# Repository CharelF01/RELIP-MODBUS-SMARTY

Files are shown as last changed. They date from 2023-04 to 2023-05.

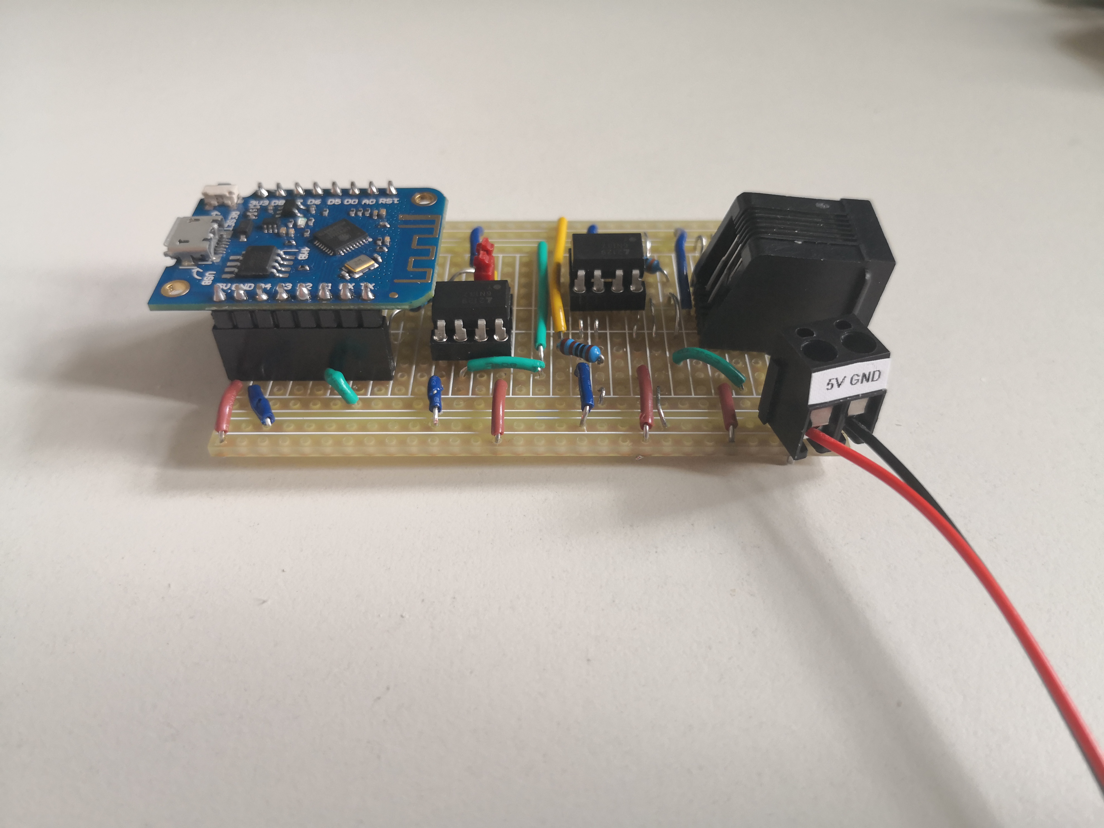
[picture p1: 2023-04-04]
Photos/Smarty Simulator/IMG_20230223_134927.jpg

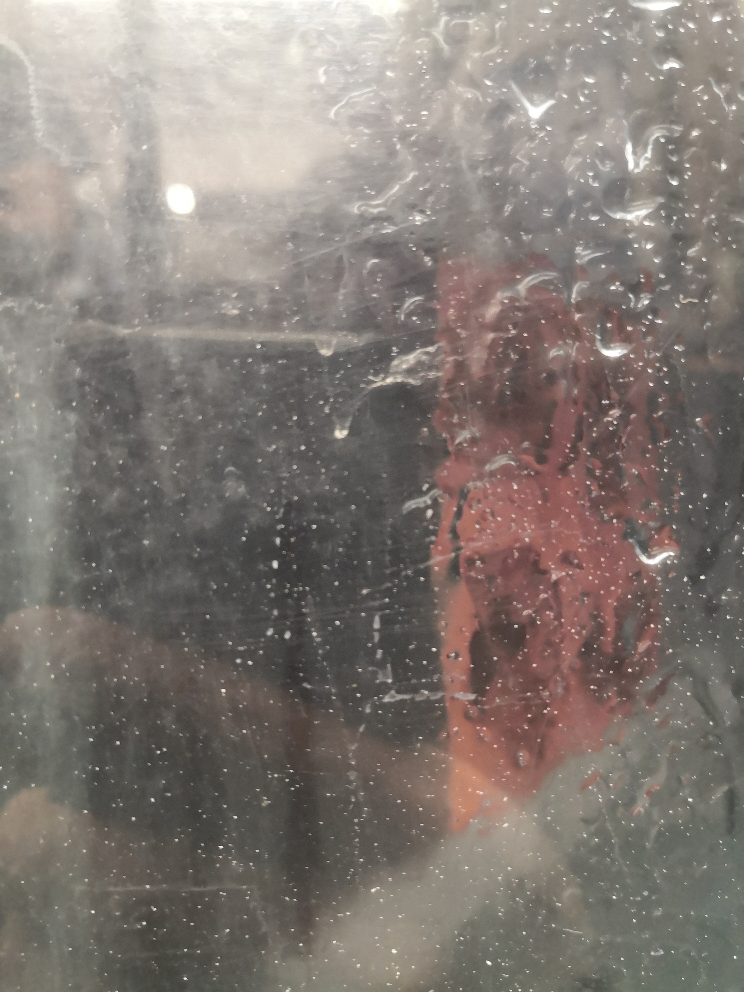
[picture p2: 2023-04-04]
Photos/Smarty Modbus/IMG_20230323_113627.jpg

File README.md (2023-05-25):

# RELIP
This project was done in the scope of the BTS-Internet of Things in the Lycée des Arts et Métiers Luxembourg with the help of Bâtiment Public Luxembourg.
The Real Life Project's objective was to make a functioning device that decrypts the data from the luxembourgish smart electrical meter and sends it out via ModBus TCP and/or RTU.

Mark received on Project: 17.5/20

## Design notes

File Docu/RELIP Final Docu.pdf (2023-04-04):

# RELIP SMARTY MODBUS

Feil Charel

### MARCH 31, 2023

BTS-IOT
Lycée des Arts et Métiers
Real Life Project 2022/2023 1, rue de l’école,
Bissen L-7768
RELIP
Supervisors:
THIERRY BERNARD
JEAN DAUBENFELD
ROBERT FISCH
GILLES GARDULA
GAETAN HOLDERBEKE
GUY WEILER

Feil Charel | 31.03.2023

## Table of contents

1 | Description of the task | 2
2 | Introduction | 3
2.1 | Step by step description | 3
3 | Main Part | 4
3.1 | List of material/ electronics | 8
3.2 | Logical schema of my infrastructure | 10
3.3 | Electronic circuit schema | 12
3.4 | Pictures of the final product | 15
3.5 | Testing table | 4
3.6 | Description of firmware | 17
3.7 | Retrospective analysis | 21
3.8 | Market analysis | 21
4 | Executive summary | 22
5 | Bibliography and list of sources | 23
6 | Executive summary | 7
7 | Acknowledgements | 24
8 | Declaration of autonomy | 25

## 1 Description of the task

The project given by our teachers consisted of 2 main parts.
Firstly, we needed to build a smarty simulator. We needed to do this as a convenience and safety measure for the class. This would enable us to work on our main projects the whole time without needing to wait for another person to be finished using the only smarty meter that we have. To build this we had a limited timeframe in order to being able to finish the main project in time. By the end of the given deadline, the smarty simulator needed to be working 100% and we needed to make a report on how and what we did.
Secondly, the main project was to build a smarty reader, which can decrypt the data received from the smarty simulator/meter and send it out via Modbus TCP and Modbus RTU. Furthermore, our product needed to be easily configurable by the end user.

## 2 Introduction

## 2.1 Step by step description

2.1.1 Smarty Simulator

My simulator simply sends out data when it’s connected to a power source of 5 Volts. However, for it to be able to send the data, you need to remove the only jumper on the board while bootup, because the connected pin is needed for the boot sequence. Afterwards, you put the jumper back on and the simulator will send data when the required triggers arrive. These are that a request is being sent to the simulator and that a non-blocking delay of 10 seconds has been passed. Then it will send data to the receiver on the other end. The simulator only sends pre configured data, which is hardcoded into the microcontroller. This is good to check reliability and be sure that all the data received by the reader is the data sent.

2.1.2 Smarty Modbus

My smarty Modbus device consists of three parts.
The configuration, which at first startup or after a reset is being shown on the access point at the IP address http://192.168.168.168 , which was given by our teachers. In this configuration, the end user can firstly decide whether they want to use RTU (RS485), TCP/IP (over ethernet) or WIFI (also TCP/IP, but named differently to reduce confusion). These are three different pages where the end user can enter all the necessary details for a successful configuration and operation.
The encryption key needs to be entered on all of the configuration pages.
In the RTU configuration page, the end user needs to enter the bitrate for the Modbus line, the slave address and the configuration for the transmission, so the Stop bit and parity.
In the TCP/IP configuration page, the end user needs to enter the IP addresses for the device itself, the gateway, subnet and DNS.
The WIFI configuration page is nearly the same as the TCP/IP one, only that the end user needs to enter the WIFI SSID and password additionally to the IP addresses asked.
After having entered all the data for the selected transmission mode, the end user needs to press the “Submit” button and the data is being saved on the device and it restarts.
The Access point reopens after bootup, so that the end user has the ability to reset the device if needed. If it isn’t necessary, the end user needs to wait 2 minutes and then the main program for the transmission via the selected Modbus is being started.

## 3 Main Part

## 3.1 Project progress

3.1.1 Smarty Simulator

3.1.1.1 Initial thoughts
One of the first things I did when we got the assignment and deadline for the simulator was to research how the optocouplers we needed to use work. Then I needed to firstly draw a functioning circuit and solder it in place on a circuit board given by our teachers. (Note to avoid confusion: the circuit wasn’t etched on the board)
At the beginning of this task, I thought that this could go rather fast if all things go well and I could focus earlier on the main part of the project.
3.1.1.2 Research
I mainly researched how the optocouplers worked, because I’ve never worked with these chips and I wanted and needed to understand them before using them. During my research, I found this fitting picture:

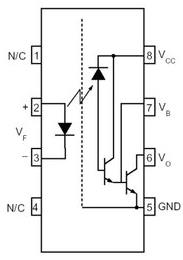
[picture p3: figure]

Then I needed to research the datasheet for the optocouplers and to calculate the needed resistors accordingly.

As shown in the picture, the input and output side are isolated (indicated by the dotted line). The input signal is transmitted via an LED on the input side to a light sensitive diode, which then activates the transistors to put out the signal on the output pin.

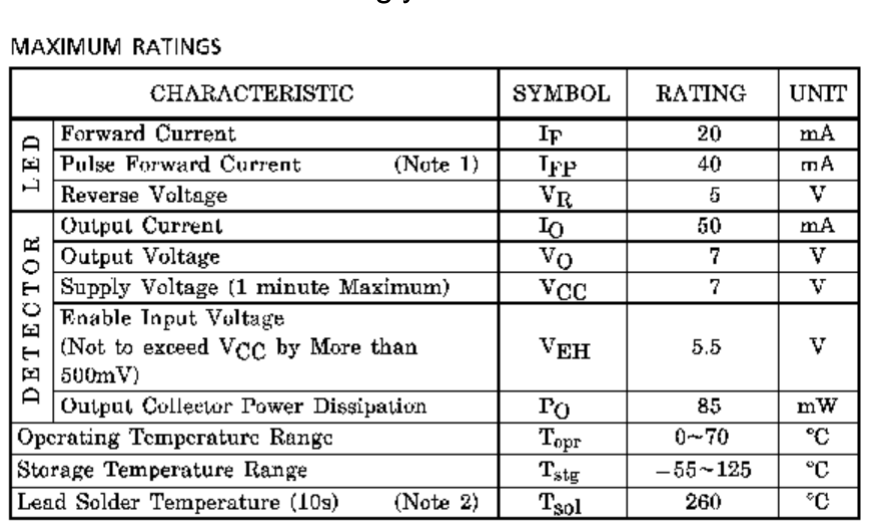
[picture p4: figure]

3.1.1.3 Calculations
The operating voltage for the internal LEDs is written as 1,7V and the maximum current is 20mA. I took 10mA as the forward current to not overstress the LED. The calculations needed to be done twice, once for the 5V side, from the RJ12 port and once for 3,3V for the ESP8266 side.
The calculations: ⁵V−1.7V
10mA

= 330Ω |

3.3V−1.7V
10mA

= 160Ω

3.1.1.4 Drawing the schematic
Then I researched examples on how to connect an optocoupler and found out that the output pin needs to be pulled up to 5V, so VCC (in most cases) or to the wanted voltage. In our case, the side going to the RJ12 port needed to be pulled up to 5V and the side going to the ESP8266 needed to be pulled up to 3,3V. In the beginning, I had both sides pulled up to 5V, which I thankfully realized in time with some help. Before putting all the components together, I drew a schematic in Eagle and asked to verify the circuit before I built it.

3.1.2 Smarty Modbus

3.1.2.1 Initial thoughts
One of the first things I thought when asked to make this product was that I had no Idea how Modbus worked and how to decrypt the received data from the smarty. We needed to do this already in an exercise during our course, but I didn’t finish it because I didn’t understand it that well that time. The decryption would become my main focus at the beginning of the project, because this seemed to be the biggest hurdle for myself at that time.
For the RS485, I knew that we needed to use a similar chip than the one we used in an exercise during our course, so I didn’t worry about that too much.
3.1.2.2 First tests
The first thing I wanted to get working was the receiving of the data and the decryption, because as I stated before, these were my main concerns at the beginning. To save some time later, I already used the RS485 chip as my serial port for debugging, which was no issue at all.
It took me some time to receive all the data correctly, but eventually I got it. Then I concentrated on the decryption, which previously gave me some headaches, but in this project it all came together, and I finally understood how to use the given libraries and could interpret the data correctly.
The next thing I tested was the Ethernet module, for that I needed the Ethernet library and simply connect the module to the ESP8266. To make sure that the module would connect to the network, I took an example code from the library and tested the connection and if it would automatically reconnect if the cable was pulled out and plugged back in.
After that, I tested the Modbus RTU with the RS485 chip by simply adding some registers and adding random values into these registers. I had some issues with this, because the software I used for reading out these registers often gave me an error that the request timed out or an invalid data request.
3.1.2.3 Managing the project
My main focus of the project was the code, because we needed to deliver something that works, and the code and the circuit are the most important pieces to this.

This means that I dedicated most of my time to the code and making sure everything would work as I intended. This was more work than I initially anticipated, but I managed to finish in time. This resulted in the design lacking a bit of finishing, but overall, I’m happy with my time management of this project.
3.1.2.4 Code
My code is far bigger than I anticipated and I’m certain that I could save a lot of space if I were to optimize some functions or write it differently, but it works the way I intended it. It was my main focus, so I dedicated all my time to this, that it works and not so much on the case. I had a lot of problems at the beginning to receive the data correctly and to decrypt the message, but I managed to do it successfully in a few days. Then I needed to concentrate on where and how the values from the smarty meter would be saved.
This took a lot more time than I anticipated, I made a lookup table consisting of the OBIS codes received from the smarty meter, their description, the register where it begins to save into, how many registers are being used for that value and a multiplication value to make the values the same unit as the ones from the SOCOMEC, which all of us based ourselves on. This took so long because many values from the smarty weren’t read by the SOCOMEC and therefore not saved in their registers. This led to a lot of confusion whether we needed to save these in random registers or not at all and some separated values from the smarty were only one register in the SOCOMEC, which meant that we needed to make a conversion. There was a lot of confusion around where to save everything, but in the end, I think everyone managed to use the same registers for everything and has their data in the same units. 3.1.2.5 Making the PCB
The PCB design was done only in a few days, because of the time constraints to get the code working properly and the availability of the room to make the PCB itself. The routing was a bit difficult, but in the end I managed to get everything routed correctly, except the one error I already mentioned in the circuits which still persists in my PCB. It still works, but this could explain some errors while reading from the RS485. 3.1.2.6 Designing the case
The case design was one of the last steps I made for this project, because it was obvious from the task given that the product needs to be working at the end and not necessarily need to look the best.
I based it all off of my PCB and designed the case around it so that it would hold the PCB in place, fit into the smarty and that the ports are accessible from the front. First idea:

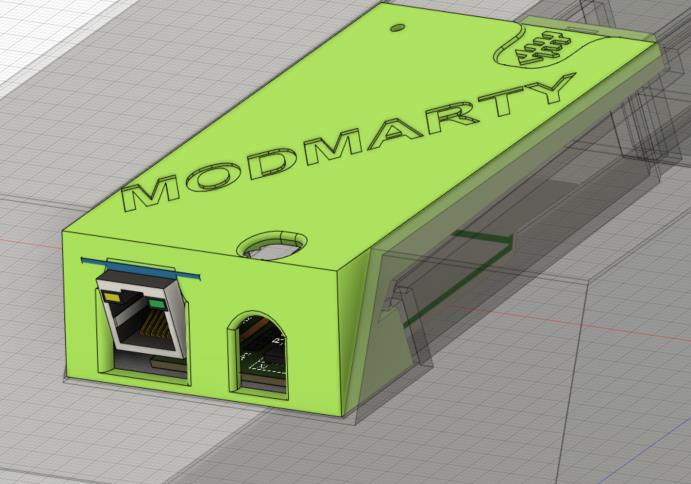
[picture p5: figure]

Final Design:

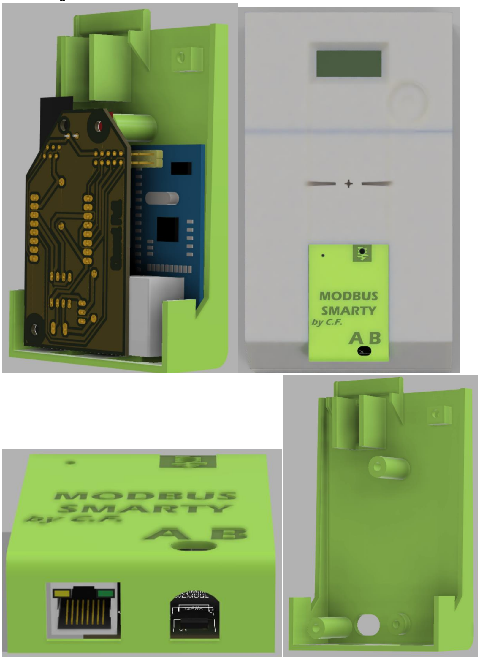
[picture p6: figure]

In my final design, I also implemented a screw hole on the upper left corner to screw the device in place. I also made some flanges to keep the cable in place on the bottom.

## 3.2 List of material/ electronics

3.2.1 Smarty Simulator

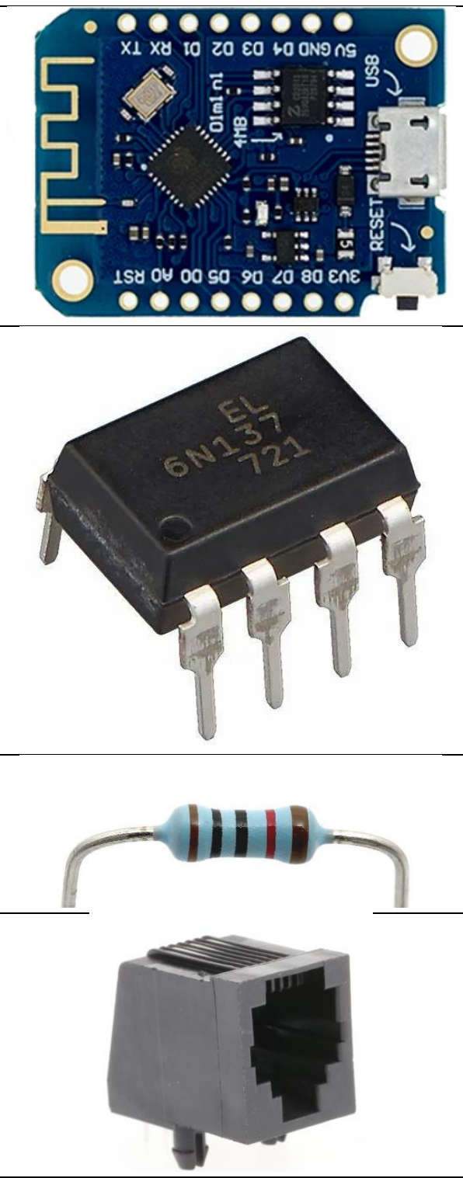
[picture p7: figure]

ESP8266

Optocoupler 2x

Resistor 3x

RJ12 Connector

3.2.2 Smarty Modbus

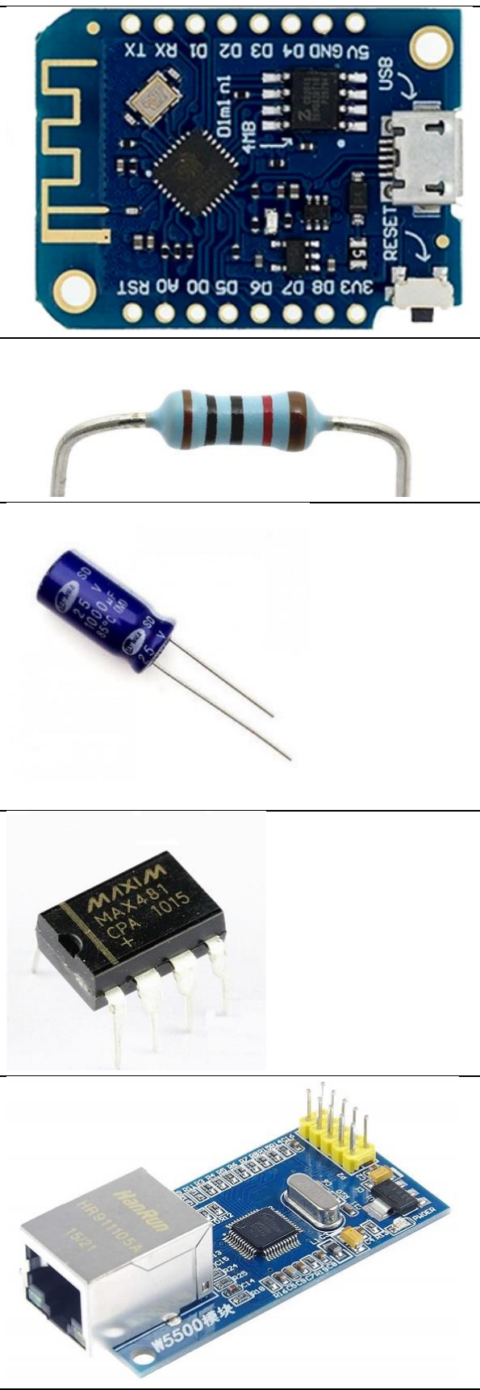
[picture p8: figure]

ESP8266

Resistor 2x

1000uF Capacitor

MAX485 CPA

Ethernet Module W5500

## 3.3 Logical schema of my infrastructure

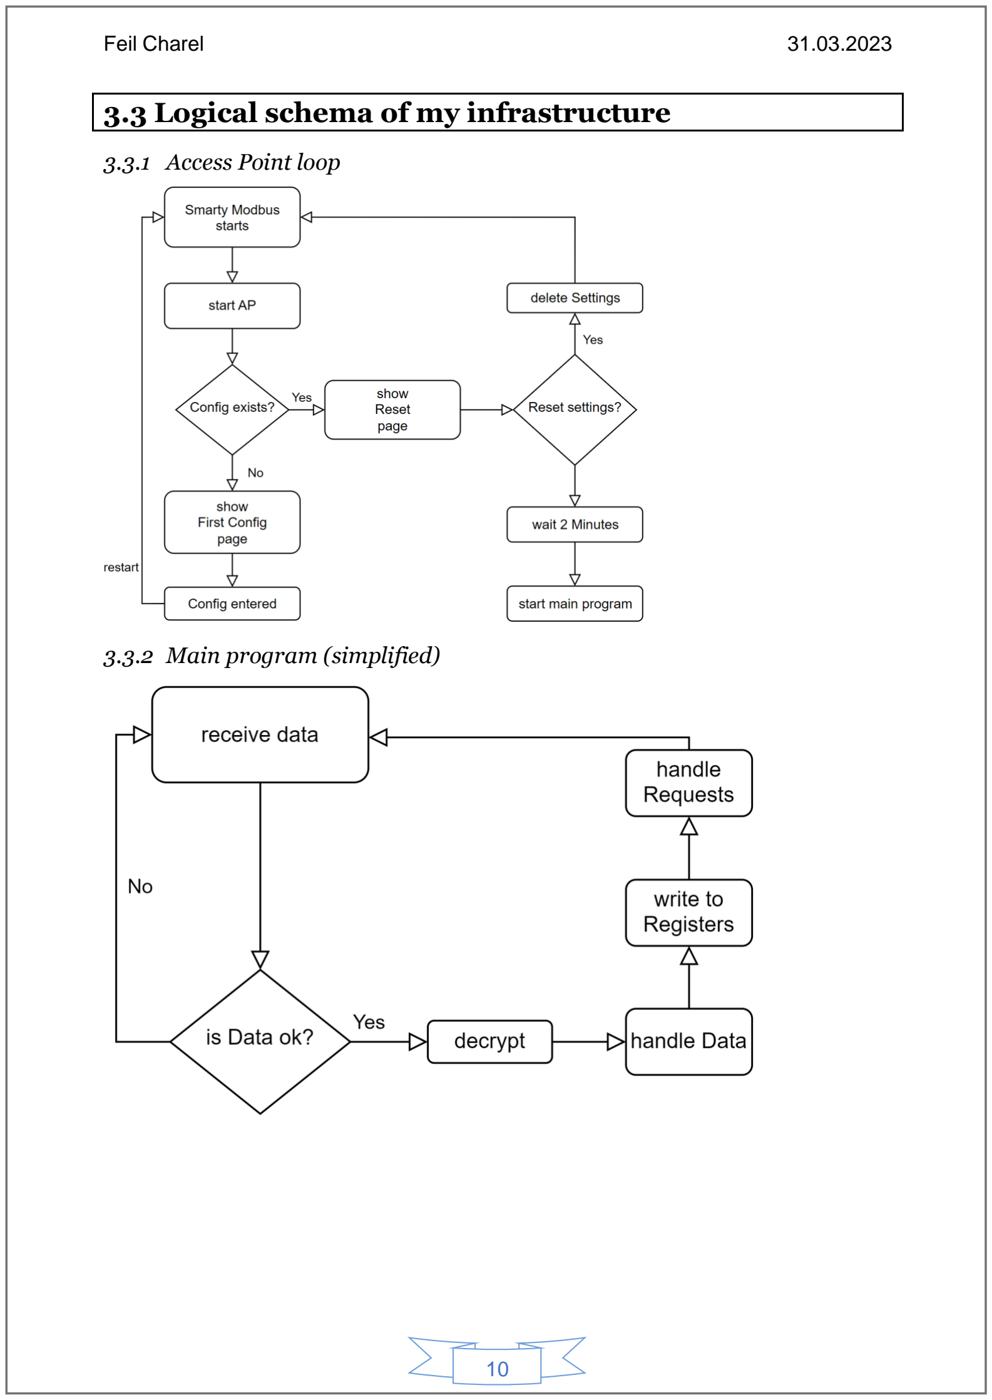
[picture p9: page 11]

3.3.1 Access Point loop

3.3.2 Main program (simplified)

3.3.3 Lookup Table

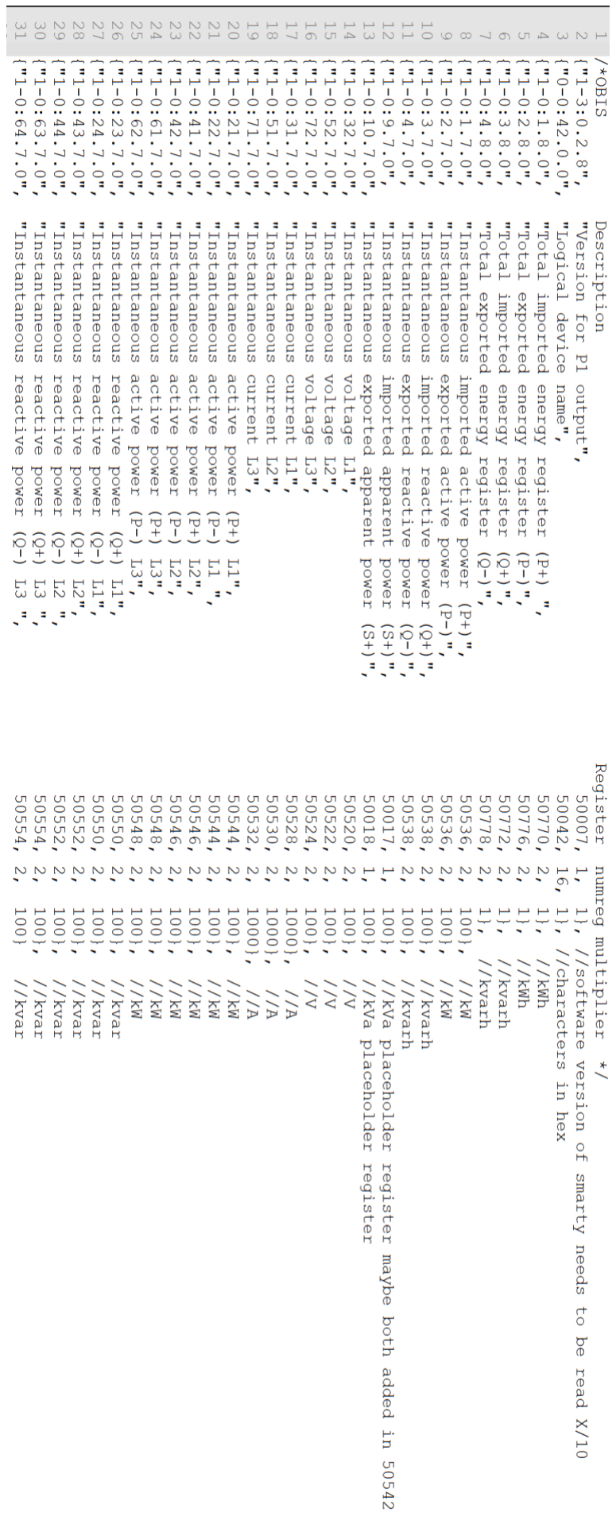
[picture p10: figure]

## 3.4 Electronic circuit schema

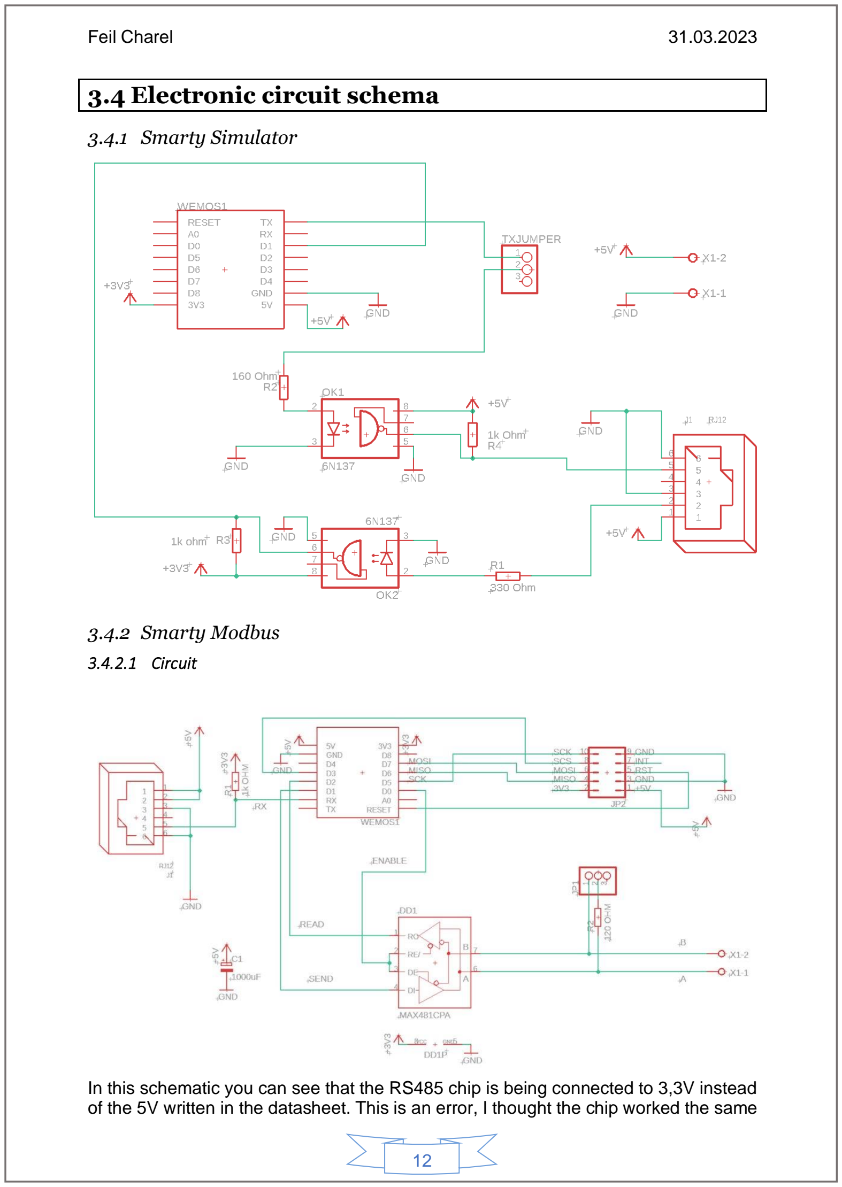
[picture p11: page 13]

3.4.1 Smarty Simulator

3.4.2 Smarty Modbus

3.4.2.1 Circuit

In this schematic you can see that the RS485 chip is being connected to 3,3V instead of the 5V written in the datasheet. This is an error, I thought the chip worked the same

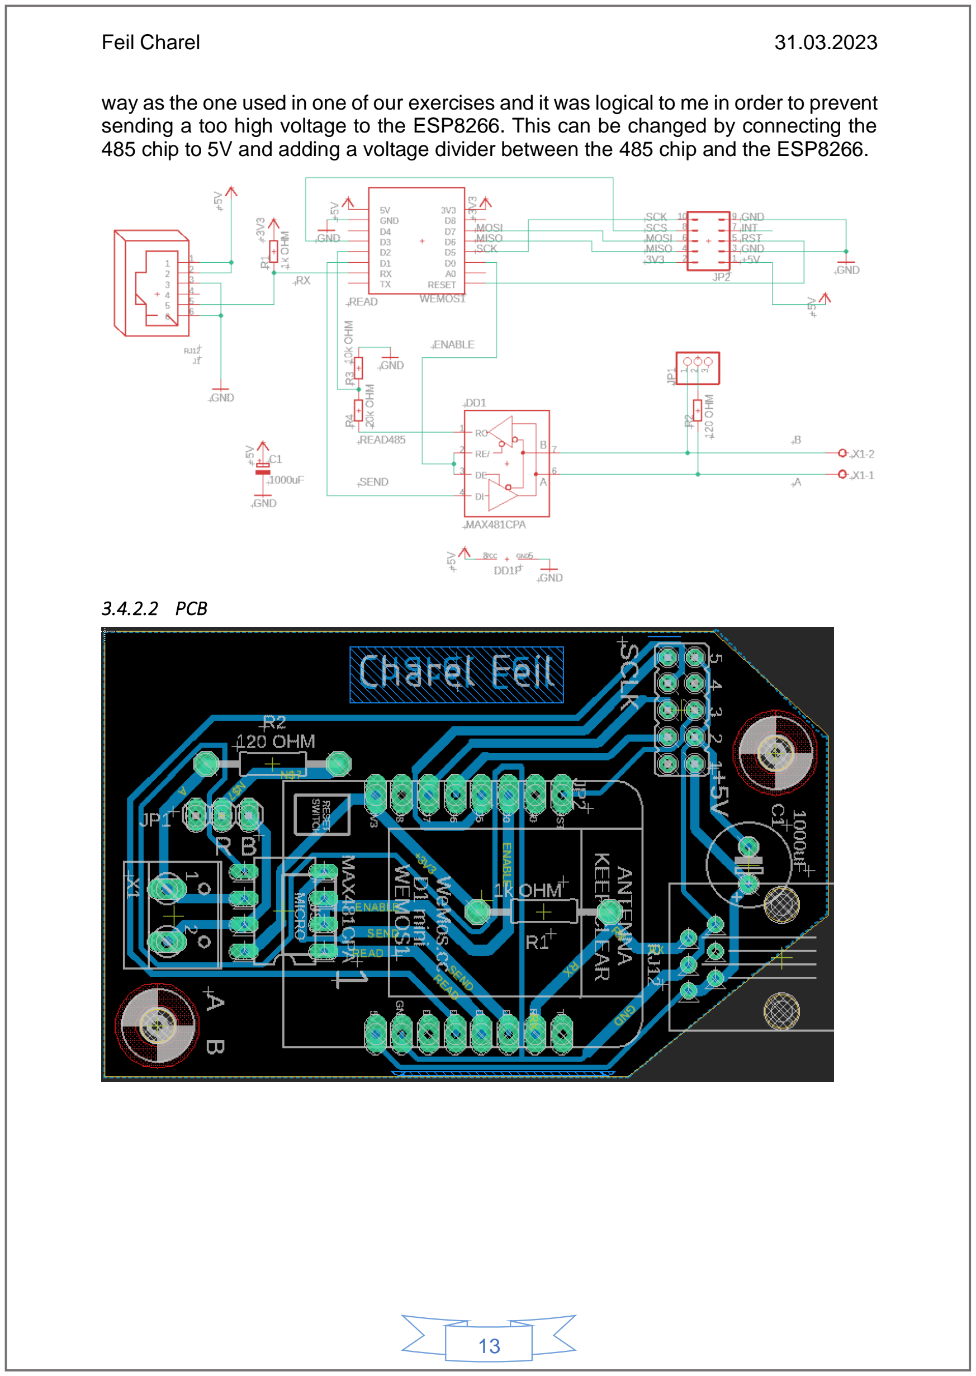
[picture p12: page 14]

way as the one used in one of our exercises and it was logical to me in order to prevent sending a too high voltage to the ESP8266. This can be changed by connecting the 485 chip to 5V and adding a voltage divider between the 485 chip and the ESP8266.

3.4.2.2 PCB

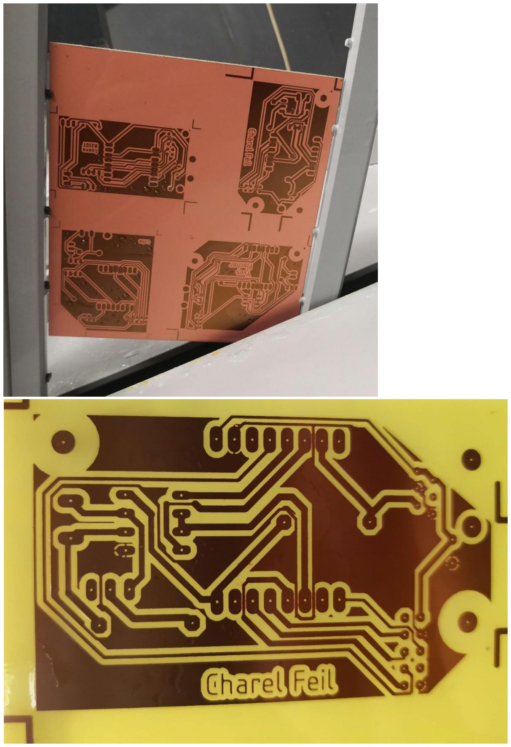
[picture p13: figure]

## 3.5 Pictures of the final product

3.5.1 Smarty Simulator

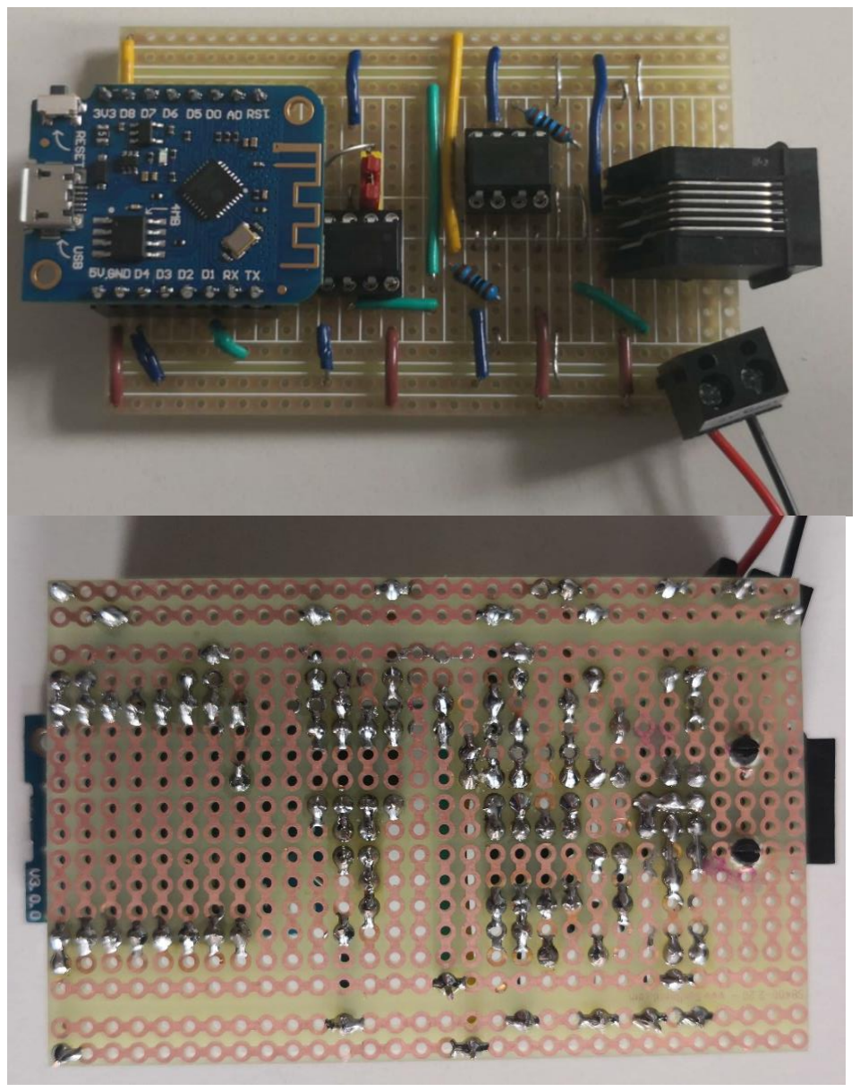
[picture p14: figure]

3.5.2 Smarty Modbus

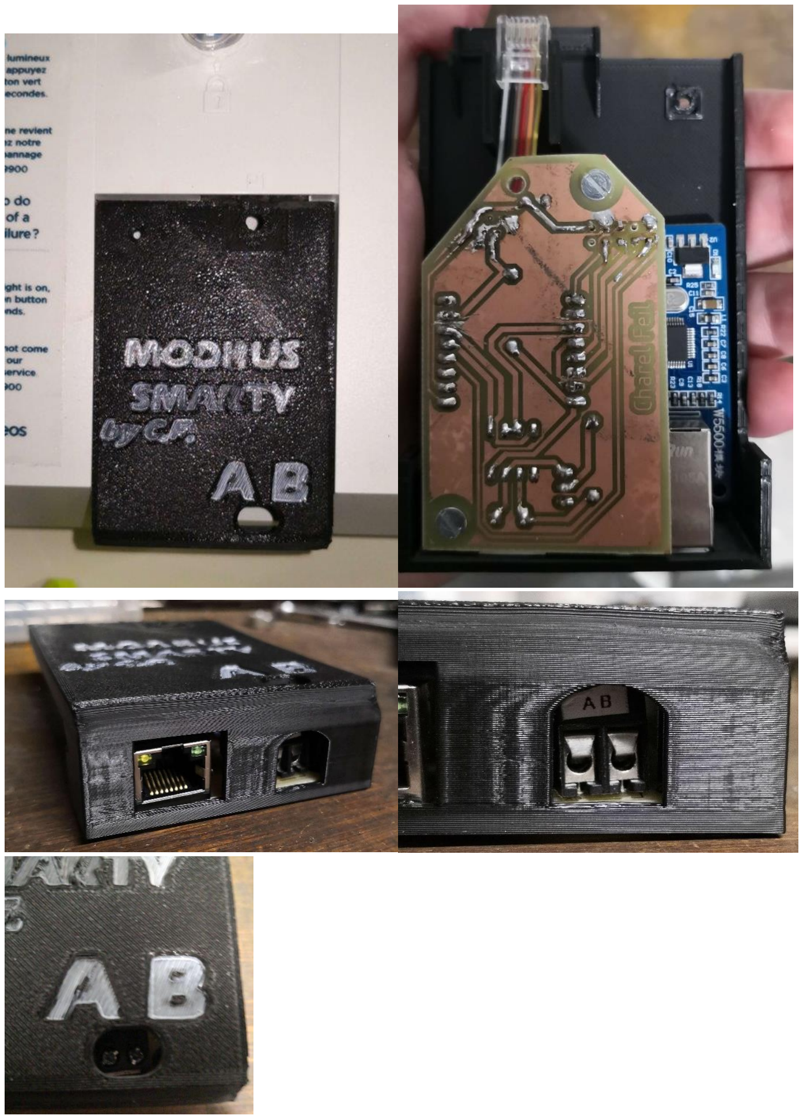
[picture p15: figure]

## 3.6 Description of firmware

You can find the flowcharts explaining the code roughly here.
When my device first boots up, it starts an Access Point (from hereon AP) under the name “Charel AP” (to avoid confusion in class), if the product were to be released to the public, I would change the name to a more appropriate one. After the AP is started, the device looks if a configuration has already been saved on it. If it hasn’t found one, then it continues to show the configuration pages to the user under the IP Address http://192.168.168.168. I made 3 different pages for RTU, TCP/IP and TCP/IP over WIFI, the starting page is RTU, so the user already sees some input and not only 3 closed tabs are being shown. The encryption key always needs to be entered, but The first configuration page of RTU looks like this:

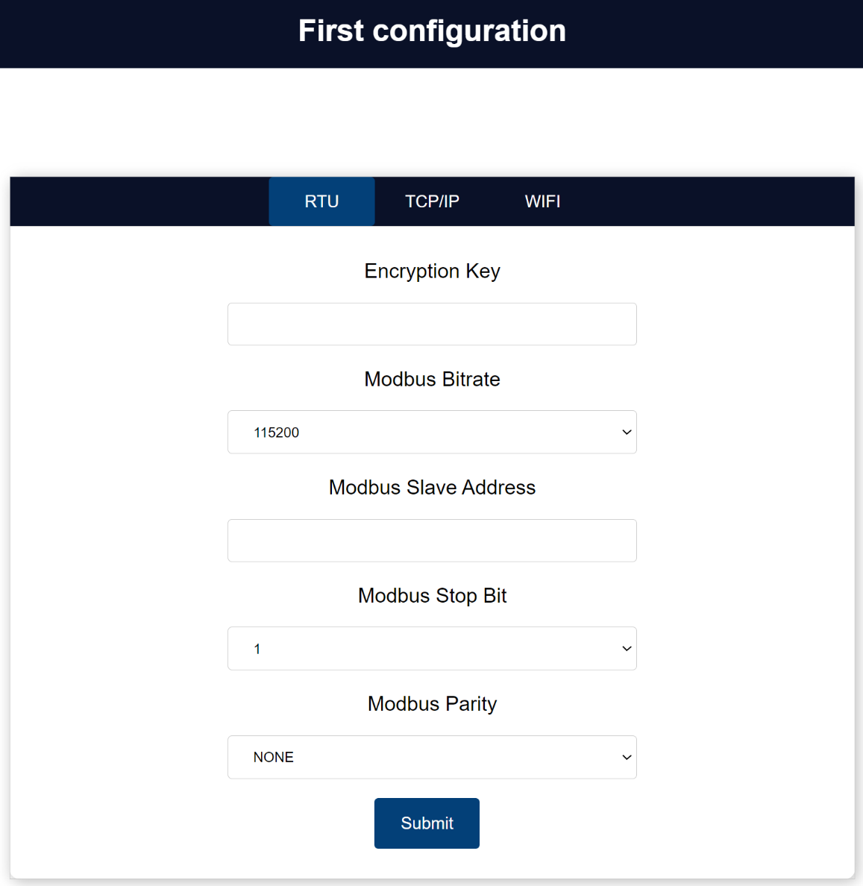
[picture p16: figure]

Here you can see that the user needs to enter all the necessary data for the Modbus that a successful transmission of data can be made. For RTU, the important fields for the data transmission would be the Bitrate, stop bit and parity, the slave address is for the Modbus to be able to identify which device it is.
The first configuration page of TCP/IP looks like this:

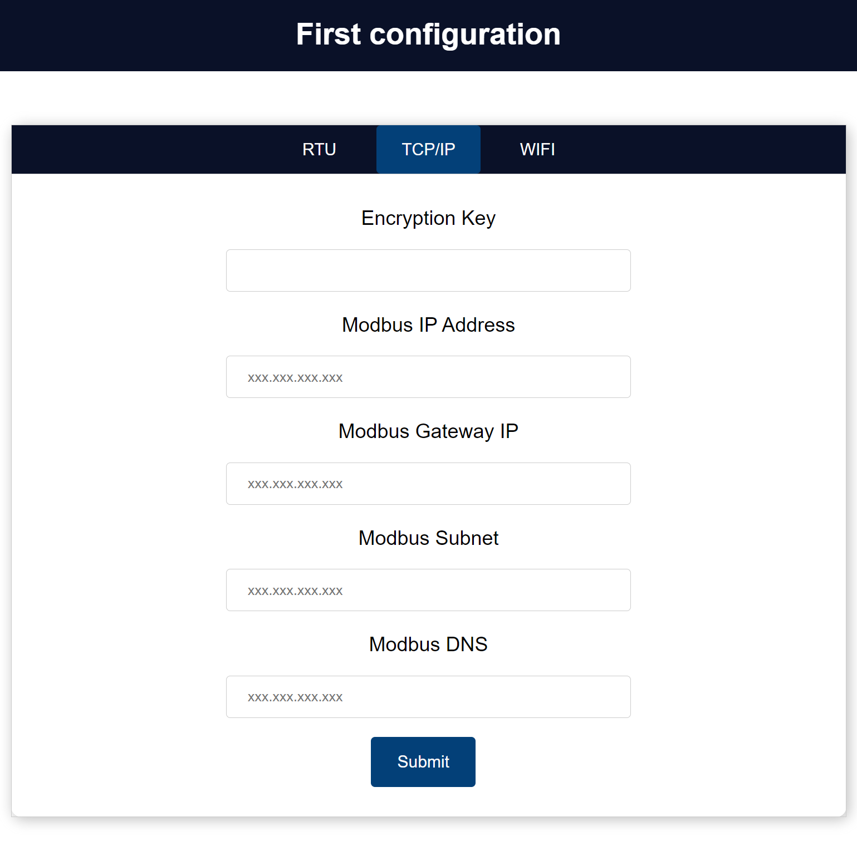
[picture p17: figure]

For TCP/IP the end user needs to enter the IP address of the device, the gateway and DNS IP addresses and the subnet mask of the network. These are necessary to ensure a good connection to the network with a static IP.
The first configuration page of the WIFI page looks like this:

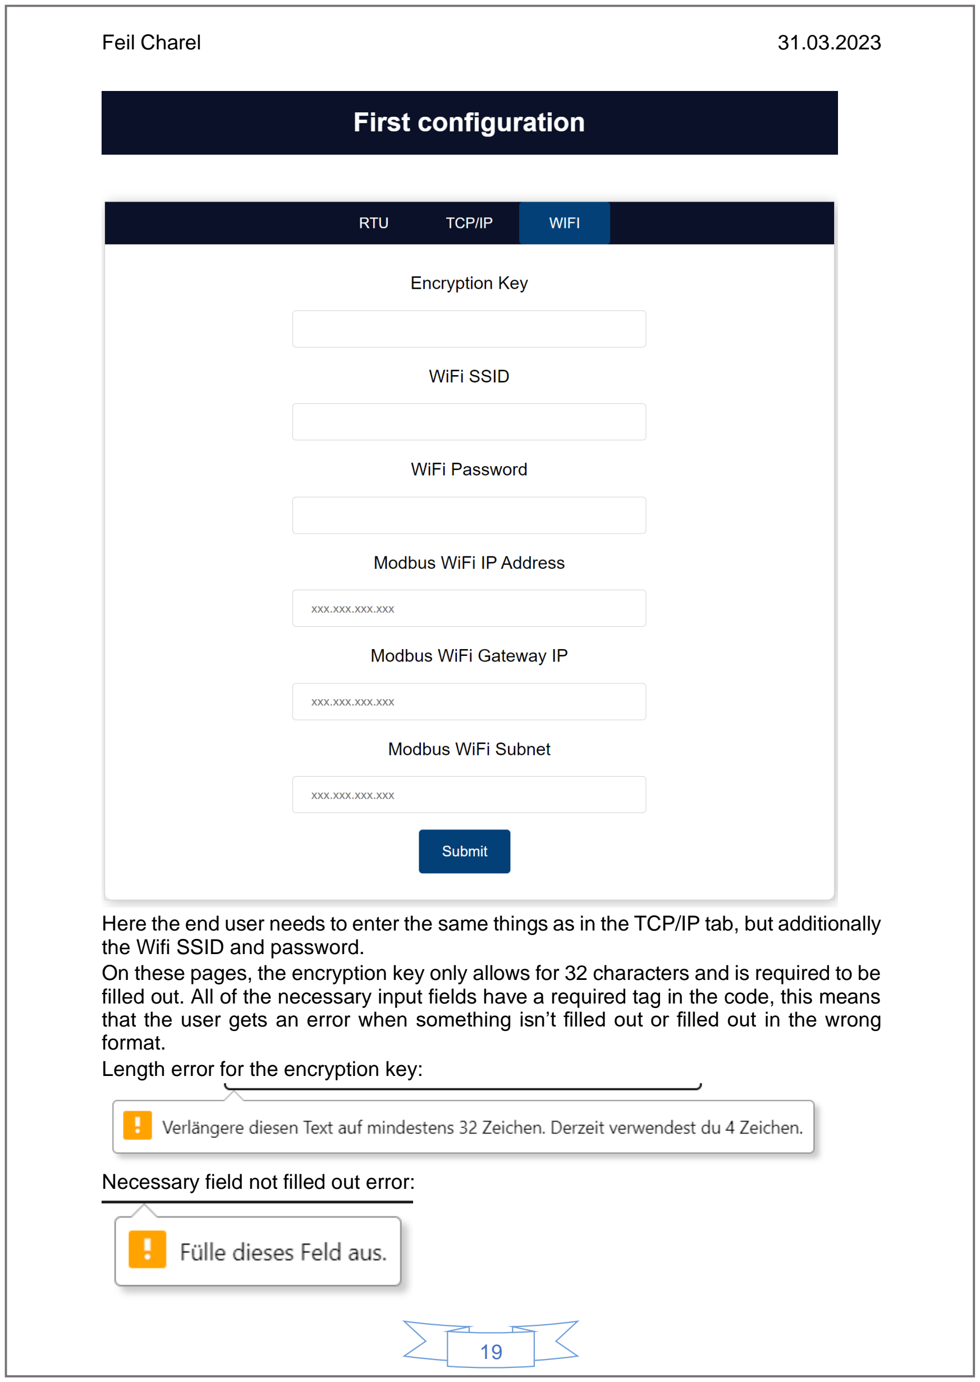
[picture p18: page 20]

Here the end user needs to enter the same things as in the TCP/IP tab, but additionally the Wifi SSID and password.
On these pages, the encryption key only allows for 32 characters and is required to be filled out. All of the necessary input fields have a required tag in the code, this means that the user gets an error when something isn’t filled out or filled out in the wrong format.
Length error for the encryption key:

Necessary field not filled out error:

When everything is filled out correctly, the user needs to press the “Submit” button and the device restarts.
After it’s booted up again, it starts the AP again and checks if there exists a configuration and now it does. This means that the Reset page is being shown, so that if any values need to be changed or any reconfiguration needs to be done, the user can reset the device and start over.
The reset page looks like this:

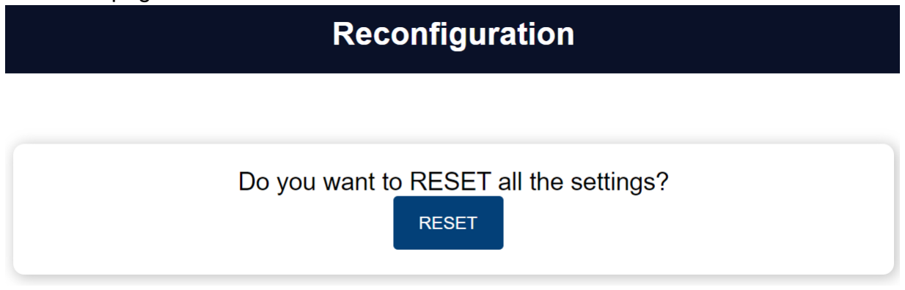
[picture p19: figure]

The user needs to press the reset button to reset and restart the device.
If the user doesn’t want to reset it, they need to wait 2 minutes for the AP to close. Then the device will start with Modbus.

Finally, when everything is configured correctly, the device will read the data received from the smarty meter and decrypt it.
Then the device will retrieve the values from the data by searching for the correct OBIS codes, extracting the number or characters, make calculations for the special registers and convert all of them into the right units, converting them into the correct format (16bit unsigned int) and writing them to the registers. This is done with my lookup table. Some values were too big for 16bit unsigned integers, that’s why I needed to make a conversion from a 32bit unsigned integer to 2 16bit numbers by first masking the first 16 bits and then the last 16 bits.
Then the values are available in the selected Modbus and can be read.

## 3.7 Retrospective analysis

Overall, I am pretty happy how my project turned out. This time, I managed my time a lot better than in the projects before. I struggled a bit with the code, but I managed to make it all work together.
For this project, we had a clear guideline and description of the task, which helped me a lot in completing it. Furthermore, the RELIP has a real function and use afterwards. This makes a project a lot more interesting and more appealing to work on.

## 3.8 Market analysis

There is no other device like this on the market, except a complete electrical meter which directly sends the data via Modbus. These are a lot more expensive than our solution if you want the electrical data from the smarty via Modbus.
I think this would be a high demanded project for big companies like “Batiment Public”.

## 4 Executive summary

The device is easily configurable by the user and can be reset if needed.
It also receives the data from the smarty reader and decrypts it.
Then it puts it in the Modbus registers, and it can be read by the user via the selected Modbus interface.

## 5 Bibliography and list of sources

1. https://github.com/emelianov/modbus-esp8266
2. https://www.weigu.lu/microcontroller/modbus/index.html
3. https://www.weigu.lu/tutorials/sensors2bus/04_encryption/index.html
4. https://www.weigu.lu/microcontroller/smartyReader/index.html
5. https://smarty.creos.net/wp-content/uploads/DutchSmartMeterRequirements.pdf (https://smarty.creos.net/wp-content/uploads/DutchSmartMeterRequirements.pdf)
6. https://media.bluestonepim.com/50098aaa-684d-40aa-945d-038656764549/beb48000-69ec-449a-8cf1-30056ac36c6c/k8gc14BCCzRT4S9XPtMeBnpHe/APNGQdFVfFmb3x7po9SC 1Mce8.pdf (https://media.bluestonepim.com/50098aaa-684d-40aa-945d-038656764549/beb48000-69ec-449a-8cf1-30056ac36c6c/k8gc14BCCzRT4S9XPtMeBnpHe/APNGQdFVfFmb3x7po9SC1Mce8.pdf)
7. https://www.luxmetering.lu/pdf/SPEC%20-%20E-Meter_P1_specification_20210308.pdf (https://www.luxmetering.lu/pdf/SPEC%20-%20E-Meter_P1_specification_20210308.pdf)

## 6 Acknowledgements

Special thanks to Yves Fischer, Luka Theisen and Luana Do Vale Daniel for helping me all around the project.

## 7 Declaration of autonomy

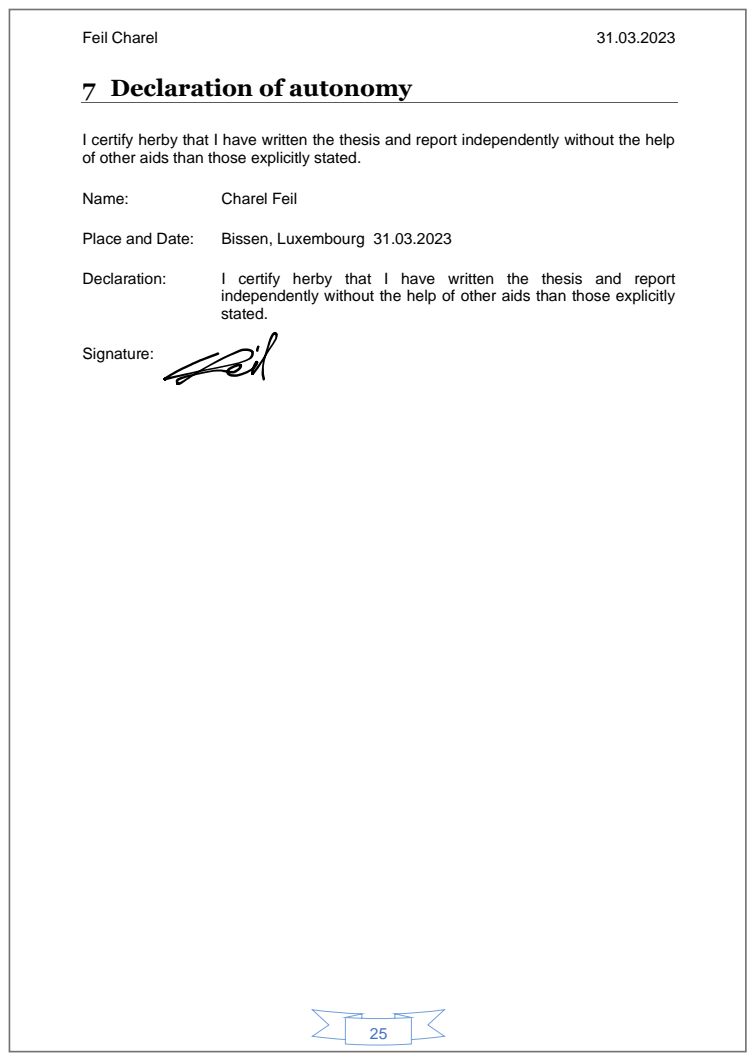
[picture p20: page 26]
Name:; Charel Feil; Place and Date:; Bissen, Luxembourg 31.03.2023; Declaration:; I certify herby that I have written the thesis and report; Signature:

I certify herby that I have written the thesis and report independently without the help
of other aids than those explicitly stated.

independently without the help of other aids than those explicitly
stated.

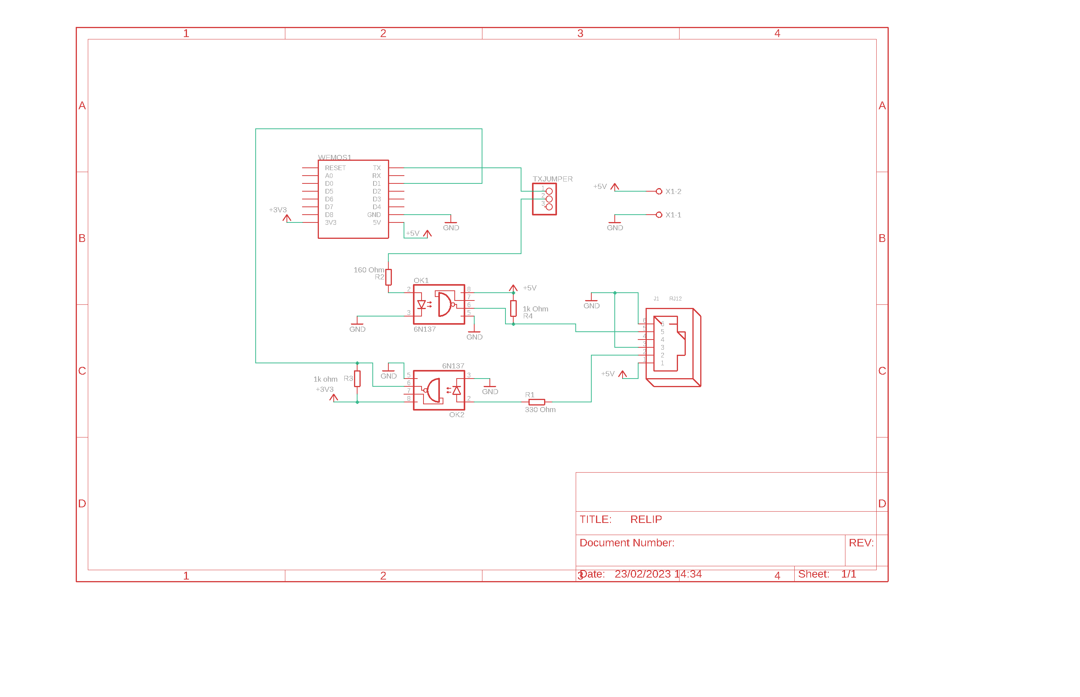
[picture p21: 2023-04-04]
Schematics/SimSchematic.png

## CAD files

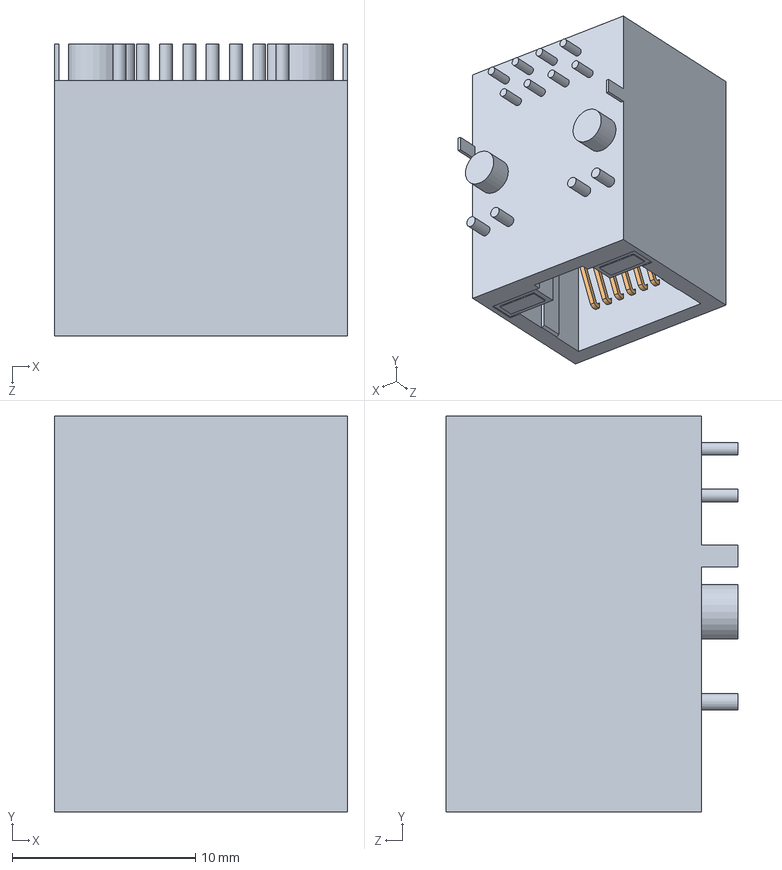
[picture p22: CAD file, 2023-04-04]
Design/W5500 ethernet module/Assembly HANRUN HR911105A.SLDASM
16.0 x 21.6 x 15.9 mm
body.stp
contact.stp x 8

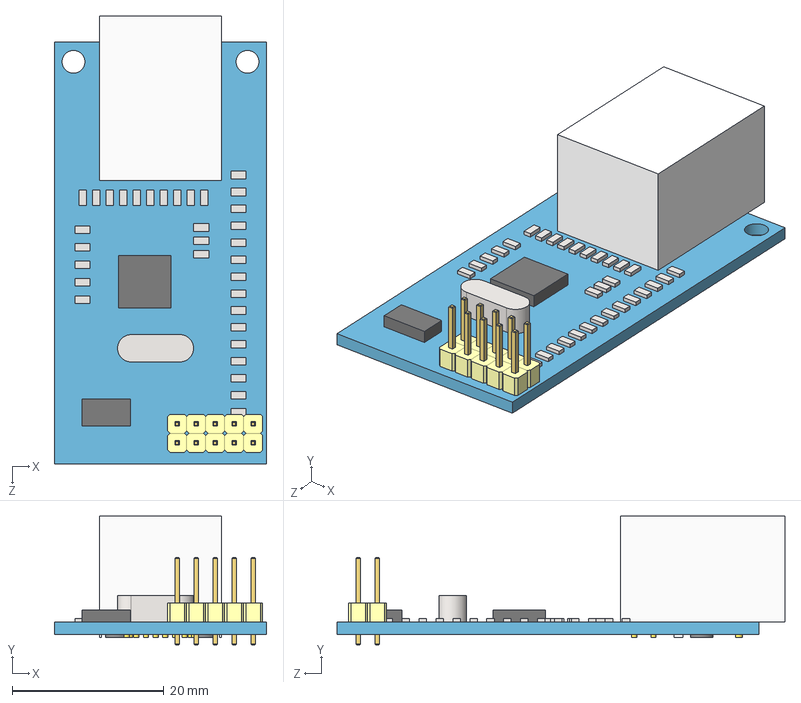
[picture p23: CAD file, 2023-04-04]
Design/W5500 ethernet module/Assembly W5500 ethernet module.STEP
27.9 x 17.0 x 58.9 mm
Plate W5500 ethernet module
body.stp
contact.stp x 8
Pins W5500 ethernet module

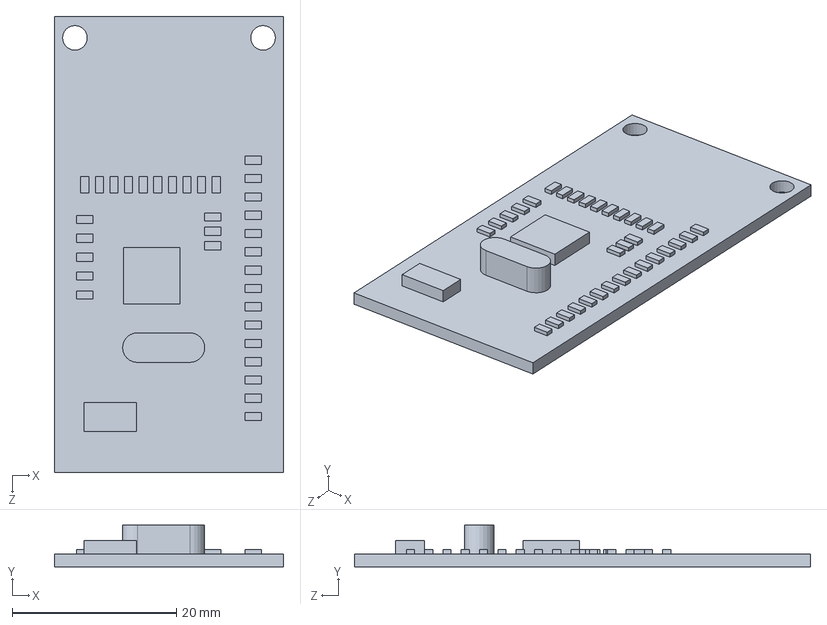
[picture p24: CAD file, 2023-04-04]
Design/W5500 ethernet module/Plate W5500 ethernet module.SLDPRT
27.9 x 5.10 x 55.5 mm

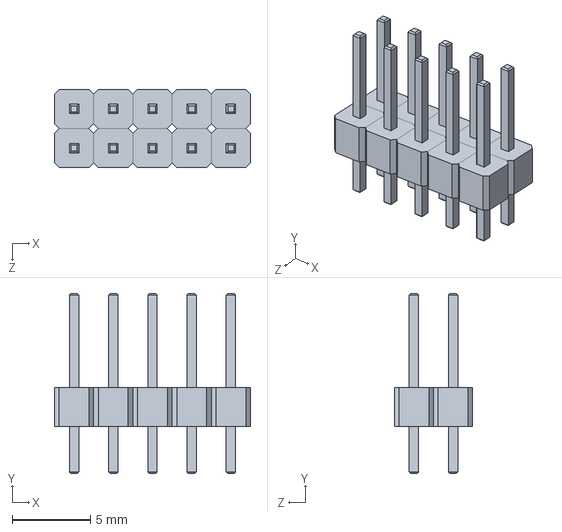
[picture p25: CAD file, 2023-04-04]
Design/W5500 ethernet module/Pins W5500 ethernet module.SLDPRT
12.5 x 11.5 x 5.00 mm

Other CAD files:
Design/W5500 ethernet module/HANRUN HR911105A.stp
Design/W5500 ethernet module/Assembly W5500 ethernet module.SLDASM

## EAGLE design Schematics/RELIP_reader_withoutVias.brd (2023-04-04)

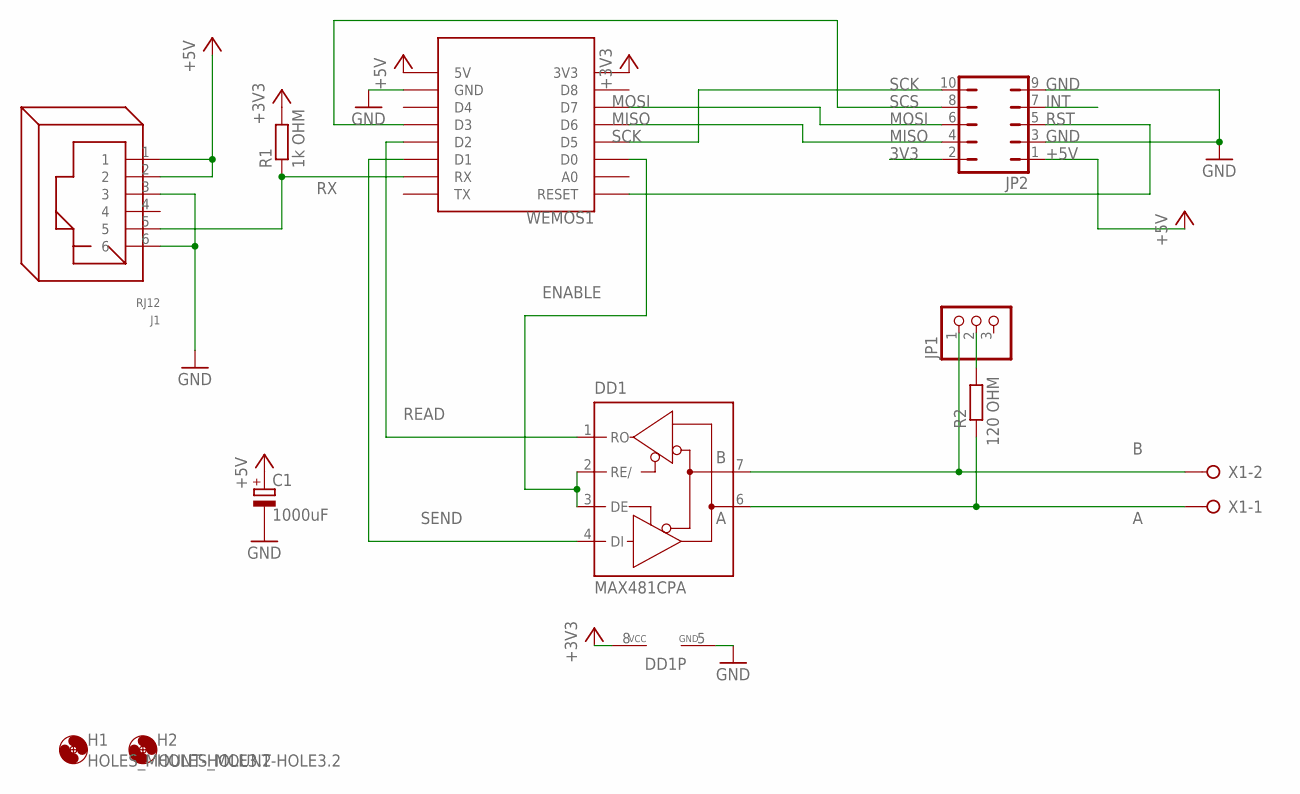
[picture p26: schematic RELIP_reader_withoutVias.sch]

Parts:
C1: 1000uF; E3,5-8
DD1: MAX481CPA; DIL08
H1, H2: HOLES_MOUNT-HOLE3.2; HOLES_3,2
J1: RJ12
JP1: PINHEAD_PINHD-1X3; PINHEAD_1X03
JP2: JP5Q
R1: 1k OHM; RCL_0207/12
R2: 120 OHM; RCL_0207/12
WEMOS1: WEMOS-D1-MINI
X1: W237-02P; W237-132

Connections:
3V3: JP2.2
+3V3: DD1.8 (VCC), R1.2, WEMOS1.3V3
+5V: C1.+, J1.1, J1.2, JP2.1, WEMOS1.5V
A: DD1.6 (A), R2.1, X1.1
B: DD1.7 (B), JP1.1, X1.2
ENABLE: DD1.2 (RE/), DD1.3 (DE), WEMOS1.D0
GND: C1.-, DD1.5 (GND), J1.3, J1.6, JP2.3, JP2.9, WEMOS1.GND
INT: JP2.7
MISO: JP2.4, WEMOS1.D6
MOSI: JP2.6, WEMOS1.D7
unnamed: JP1.2, R2.2
READ: DD1.1 (RO), WEMOS1.D2
RST: JP2.5, WEMOS1.RESET
RX: J1.5, R1.1, WEMOS1.RX
SCK: JP2.10, WEMOS1.D5
SCS: JP2.8, WEMOS1.D3
SEND: DD1.4 (DI), WEMOS1.D1

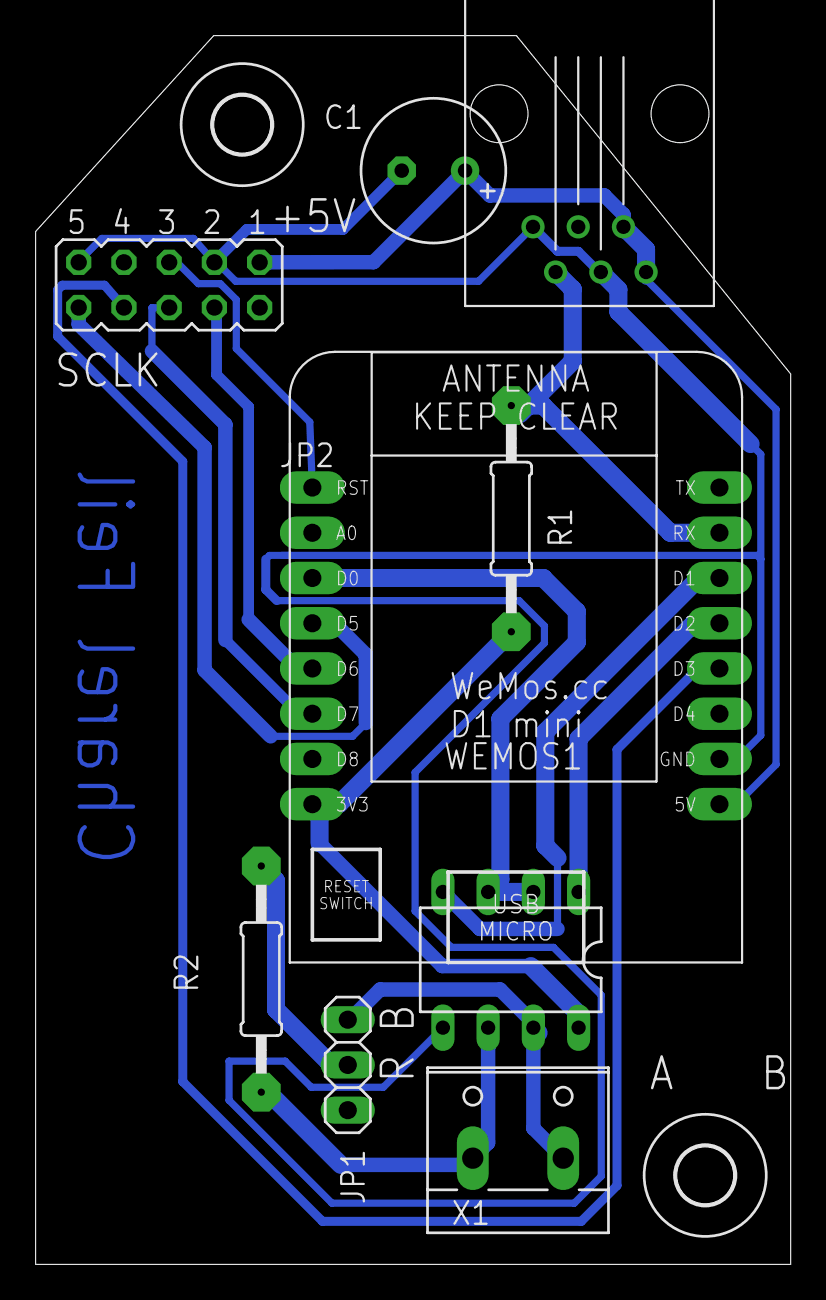
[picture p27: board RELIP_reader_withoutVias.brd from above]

Board: 2 copper layers, 42.4 x 69.0 mm, 11 parts (0 on the bottom side), 15 nets.

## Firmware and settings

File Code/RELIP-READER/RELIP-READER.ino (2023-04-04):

/*
  Charel Feil
  RELIP Reader
  BTS-IOT 2
  29/03/2023
*/
/* needed for access point*/
#include <ESP8266WiFi.h>
#include <ESPAsyncTCP.h>
#include <ESPAsyncWebServer.h>
#include <FS.h>

#include <Crypto.h>
#include <AES.h>
#include <GCM.h>
#include <SoftwareSerial.h>
#include <SPI.h>
#include <Ethernet.h>
#include <ModbusRTU.h>
#include <ModbusEthernet.h>
#include <ModbusIP_ESP8266.h>

//define pins
#define myport_TX D1
#define myport_RX D2
#define ETHCHIP_SELECT D3
#define enable_485 D0
#define APName "Charel AP"
//initialize modbuses
ModbusEthernet mbE;
ModbusRTU mbRTU;
ModbusIP mbIP;

int rtuFlag = 0;  //0 = tcp, 1=rtu, 2=wifi

/*arrays containing allowed baudrates stop bits and parities
good for checking if the correct one has been entered and easier to parse with input from ap
*/
long mBaudrate[8]{
  1200, 2400, 4800, 9600, 19200, 38400, 57600, 115200
};
uint8_t sBit[2] = {
  1, 2
};
String parityAr[3] = {
  "NONE", "ODD", "EVEN"
};

int apMode = 0;  //0= no ap, 1 = setting ap, 2= resetting ap
//initialize software serial
SoftwareSerial myport;

//define modbus ethernet mac and ip address
IPAddress ip(192, 168, 131, 122);
IPAddress gateway(192, 168, 168, 1);
IPAddress subnet(255, 255, 255, 0);
IPAddress dns(1, 1, 1, 1);
IPAddress wifiip;
IPAddress wifigateway;
IPAddress wifisubnet;
/**/
byte mac[] = {
  0xD2, 0xAD, 0xB3, 0xEF, 0xFE, 0x11
};

/*
* Code for WiFi Access Point still work in progress
* Commented to not interfere with rest for proof of concept
*/
AsyncWebServer server(80);
IPAddress apIP(192, 168, 168, 168);
IPAddress apGateway(192, 168, 168, 1);
IPAddress apSubnet(255, 255, 255, 0);

/*
IPAddress wifiIP(192, 168, 168, 168);
IPAddress wifiGateway(192, 168, 168, 1);
IPAddress wifiSubnet(255, 255, 255, 0);
*/
const int paramLength = 15;
//input parameters from webpage
String PARAM_INPUT[paramLength] = {
  "encryptionKey", "mBitrate", "mIPAddress", "mSlaveAddress", "mStopBit", "mParity", "tcpGateway", "tcpSubnet", "tcpDns", "wifiSsid", "wifiPass", "wifiIP", "wifiGateway", "wifiSubnet"
};

//paths to saved input files
String PATH_INPUT[paramLength] = {
  "/encryptionKey.txt", "/modbusBitrate.txt", "/ip.txt", "/modbusSlaveAddr.txt", "/stop.txt", "/parity.txt", "/tcpGateway.txt", "/tcpSubnet.txt", "/tcpDns.txt", "/WiFiSSID.txt", "/WiFiPass.txt", "/WiFiIP.txt", "/WiFiGateway.txt", "/WiFiSubnet.txt"
};

//Variables to save values from HTML form
String encryptionKey = "";
String ssid;
String pass;
//variables to set baudrate, stop bit, parity and slave id
long modbusBaud = 115200;
uint8_t stopBit = 1;
uint8_t SLAVE_ID = 1;
String parity = "NONE"; /**/
// File paths to save input values permanently

//define max plaintext and serial stream length
const unsigned int MAX_PLAINTEXT_LEN = 1200;
const unsigned int MAX_SERIAL_STREAM_LENGTH = 1800;
uint8_t allData[MAX_SERIAL_STREAM_LENGTH];

// define name key and aad key and name will be changeable when AP is implemented
const char myvname[] = "AES-128 GCM";                 // vector name
char mykey[] = "EBD3E604BA79E1D7CF9D2D1AB1033204";    // Key for SAG1030700089067 (16 byte)
char myAAD[] = "3000112233445566778899AABBCCDDEEFF";  // 17 byte (in Hex 34 character)

//vector struct for decryption
struct Vector_GCM {
  const char *name;
  static const byte keysize = 16;
  unsigned int datasize;
  static const byte authsize = 17;
  static const byte ivsize = 12;
  static const byte tagsize = 12;
  byte key[keysize];
  byte plaintext[MAX_PLAINTEXT_LEN];
  byte ciphertext[MAX_PLAINTEXT_LEN];
  byte authdata[authsize];
  byte iv[ivsize];
  byte tag[tagsize];
};

//lookup table struct for list of obis codes and modbus registers
struct lutStruct {
  String identifier;
  String name;
  int addr;
  int numAddr;
  int multiplier;
};

//init counter(s) and non blocking delay(s)
unsigned long counter = 0;
int prevMillis = 0;
int interval = 2000;
int prevAPMillis = 0;
int APTimeout = 1000 * 60 * 2 /**/;  //2 minutes
//init length of lookup table
const int lutLength = 30;
//init vector
Vector_GCM my_vector;
//init lookuptable with values, many commented because not needed/ not in E23
lutStruct lookupTable[lutLength] = {
  /*OBIS          Description                                          Register  numreg multiplier  */
  { "1-3:0.2.8", "Version for P1 output", 50007, 1, 1 },                          //software version of smarty needs to be read X/10
                                                                                  /*{"0-0:1.0.0",   "current date-time ",                                   50882, 2,  },  //year,month, day, hour, minute, second*/
  { "0-0:42.0.0", "Logical device name", 50042, 16, 1 },                          //characters in hex
  { "1-0:1.8.0", "Total imported energy register (P+) ", 50770, 2, 1 },           //kWh
  { "1-0:2.8.0", "Total exported energy register (P-)", 50776, 2, 1 },            //kWh
  { "1-0:3.8.0", "Total imported energy register (Q+)", 50772, 2, 1 },            //kvarh
  { "1-0:4.8.0", "Total exported energy register (Q-)", 50778, 2, 1 },            //kvarh
  { "1-0:1.7.0", "Instantaneous imported active power (P+)", 50536, 2, 100 },     //kW
  { "1-0:2.7.0", "Instantaneous exported active power (P-)", 50536, 2, 100 },     //kW
  { "1-0:3.7.0", "Instantaneous imported reactive power (Q+)", 50538, 2, 100 },   //kvarh
  { "1-0:4.7.0", "Instantaneous exported reactive power (Q-)", 50538, 2, 100 },   //kvarh
                                                                                  /*{"0-0:17.0.0",  "Active threshold (SMAX)",                              50016, 1,  },  //kVa*/
  { "1-0:9.7.0", "Instantaneous imported apparent power (S+)", 50540, 2, 100 },   //kVa
  { "1-0:10.7.0", "Instantaneous exported apparent power (S+)", 50540, 2, 100 },  //kVa
                                                                                  /*{"1-1:31.4.0",  "Threshold for maximum imported and exported current",  50019, 2,  },  //A
    {"0-0:96.3.10", "Breaker control state",                                50021, 1,  },  //bool
    {"0-1:96.3.10", "Relay 1 control state",                                50022, 1,  },  //bool
    {"0-2:96.3.10", "Relay 2 control state",                                50023, 1,  },  //bool
    {"0-0:96.7.21", "Number of power failures",                             50024, 1,  },  //int
    {"1-0:32.32.0", "Number of voltage sags L1",                            50025, 1,  },  //int
    {"1-0:52.32.0", "Number of voltage sags L2",                            50026, 1,  },  //int
    {"1-0:72.32.0", "Number of voltage sags L3",                            50027, 1,  },  //int
    {"1-0:32.36.0", "Number of voltage swells L1",                          50028, 1,  },  //int
    {"1-0:52.36.0", "Number of voltage swells L2",                          50029, 1,  },  //int
    {"1-0:72.36.0", "Number of voltage swells L3",                          50030, 1,  },  //int
    {"0-0:96.13.0", "Long message E-meter",                                 50031, 1,  },  //???
    {"0-0:96.13.2", "Long message channel 2",                               50032, 1,  },  //???
    {"0-0:96.13.3", "Long message channel 3",                               50033, 1,  },  //???
    {"0-0:96.13.4", "Long message channel 4",                               50034, 1,  },  //???
    {"0-0:96.13.5", "Long message channel 5",                               50035, 1,  },  //???*/
  { "1-0:32.7.0", "Instantaneous voltage L1", 50520, 2, 100 },                    //V
  { "1-0:52.7.0", "Instantaneous voltage L2", 50522, 2, 100 },                    //V
  { "1-0:72.7.0", "Instantaneous voltage L3", 50524, 2, 100 },                    //V
  { "1-0:31.7.0", "Instantaneous current L1", 50528, 2, 1000 },                   //A
  { "1-0:51.7.0", "Instantaneous current L2", 50530, 2, 1000 },                   //A
  { "1-0:71.7.0", "Instantaneous current L3", 50532, 2, 1000 },                   //A
  { "1-0:21.7.0", "Instantaneous active power (P+) L1", 50544, 2, 100 },          //kW
  { "1-0:22.7.0", "Instantaneous active power (P-) L1 ", 50544, 2, 100 },         //kW
  { "1-0:41.7.0", "Instantaneous active power (P+) L2", 50546, 2, 100 },          //kW
  { "1-0:42.7.0", "Instantaneous active power (P-) L2", 50546, 2, 100 },          //kW
  { "1-0:61.7.0", "Instantaneous active power (P+) L3", 50548, 2, 100 },          //kW
  { "1-0:62.7.0", "Instantaneous active power (P-) L3", 50548, 2, 100 },          //kW
  { "1-0:23.7.0", "Instantaneous reactive power (Q+) L1", 50550, 2, 100 },        //kvar
  { "1-0:24.7.0", "Instantaneous reactive power (Q-) L1", 50550, 2, 100 },        //kvar
  { "1-0:43.7.0", "Instantaneous reactive power (Q+) L2", 50552, 2, 100 },        //kvar
  { "1-0:44.7.0", "Instantaneous reactive power (Q-) L2 ", 50552, 2, 100 },       //kvar
  { "1-0:63.7.0", "Instantaneous reactive power (Q+) L3 ", 50554, 2, 100 },       //kvar
  { "1-0:64.7.0", "Instantaneous reactive power (Q-) L3 ", 50554, 2, 100 }        //kvar
};     /**/

/****** Helper functions from myself******/
void addCustomRegs() {
  //add registers for soco + number
  if (rtuFlag == 0) mbE.addHreg(50000, 0, 6);
  else if (rtuFlag == 1) mbRTU.addHreg(50000, 0, 6);
  else if (rtuFlag == 2) mbIP.addHreg(50000, 0, 6);
  //mbIP.addHreg(50000, 0, 6);
  //put soco and number in registers
  addToHreg(50000, 'S', 1);
  addToHreg(50001, 'O', 1);
  addToHreg(50002, 'C', 1);
  addToHreg(50003, 'O', 1);
  addToHreg(50005, 0X005f, 1);

  //add registers for slave id, baudrate, stop bit and parity
  if (rtuFlag == 0) mbE.addHreg(57344, 0, 4);
  else if (rtuFlag == 1) mbRTU.addHreg(57344, 0, 4);
  else if (rtuFlag == 2) mbIP.addHreg(57344, 0, 4);
  //add slave id to register
  addToHreg(57344, SLAVE_ID, 1);
  //check baudrate and set the corresponding index in register
  int baud = 0;
  while (mBaudrate[baud] != modbusBaud) {
    baud++;
  }
  addToHreg(57345, baud, 1);

  //check stop bit and set the corresponding index in register
  int stopB = 0;
  while (sBit[stopB] != stopBit) {
    stopB++;
  }
  addToHreg(57346, stopB, 1);

  //check parity and set the corresponding index in register
  int par = 0;
  while (parityAr[par] != parity) {
    par++;
  }
  addToHreg(57347, par, 1);
}
//get the data and write it to the registers
void obisToHReg(Vector_GCM &vect, lutStruct lut[]) {
  //make string with whole plaintext
  String pltxt = String((char *)vect.plaintext);
  //go through whole lookup table and search plaintext for identifiers
  for (int i = 0; i < lutLength; i++) {
    String seek = lut[i].identifier;
    int begindex = pltxt.indexOf(seek);
    //get the line beginning with the identifier
    String line = getLine(pltxt, begindex);
    Serial1.println(String(i) + ": " + line);

    //Special case for device name
    if (seek == "0-0:42.0.0") {
      //get beginning and end of String
      int subStringBegin = line.indexOf("(") + 1;
      int subStringEnd = line.indexOf(")");
      //define array size and corresponding arrays
      const int arsize = lut[i].numAddr + 1;
      byte devName[arsize];
      char tempChar[arsize * 2];
      //get the substring and convert it to a char array
      line.substring(subStringBegin, subStringEnd).toCharArray(tempChar, arsize * 2);
      //convert the hex char array to regular characters and save them in a byte array
      c_string_hexbytes_2_bytes(tempChar, devName);
      Serial1.println("\n\r Dev Name");
      //go through byte array and write it to the Registers
      for (int x = 0; x < arsize - 1; x++) {
        Serial1.write(devName[x]);
        if (rtuFlag == 0) {
          Serial1.println("TCP setting " + String(devName[x]) + "to register " + String(lut[i].addr + x));
          mbE.Hreg(lut[i].addr + x, devName[x]);
        } else if (rtuFlag == 1) {
          Serial1.println("RTU setting " + String(devName[x]) + "to register " + String(lut[i].addr + x));
          mbRTU.Hreg(lut[i].addr + x, devName[x]);
        } else if (rtuFlag == 2) {
          Serial1.println("WiFi setting " + String(devName[x]) + "to register " + String(lut[i].addr + x));
          mbIP.Hreg(lut[i].addr + x, devName[x]);
        }

        //mbIP.Hreg(lut[i].addr + x, devName[x]);
      }
    }
    //special cases for combined values
    else if (lut[i].addr == lut[i + 1].addr) {
      //get second line with values
      i++;
      String seek2 = lut[i].identifier;
      int begindex2 = pltxt.indexOf(seek2);
      String line2 = getLine(pltxt, begindex2);
      Serial1.println(String(i) + ": " + line2);
      //extract both numbers
      float num1 = (numberFromString(line, "(", ")") * lut[i].multiplier);
      float num2 = (numberFromString(line2, "(", ")") * lut[i].multiplier);
      uint32_t numToReg;
      //combine them accordingly
      if (seek == "1-0:9.7.0") numToReg = (uint32_t)(num1 + num2);
      else numToReg = (uint32_t)(num1 - num2);
      //Serial1.println(seek + " : " + String(lut[i].addr) + " : " + String(numToReg));
      //add them to the register
      addToHreg(lut[i].addr, numToReg, lut[i].numAddr);
    }
    //special case for double value, 1 line
    /*else if (seek=="1-1:31.4.0") {
        uint16_t ar[2];
        multipleNumbersFromString(line, "(", ")", "(", ")",ar);
        mbE.Hreg(lut[i].addr, ar[0]);
        mbRTU.Hreg(lut[i].addr, ar[0]);
        mbE.Hreg(lut[i].addr+1, ar[1]);
        mbRTU.Hreg(lut[i].addr+1, ar[1]);
    }*/
    //the rest
    else {
      uint32_t numToReg = (uint32_t)(numberFromString(line, "(", ")") * lut[i].multiplier);
      //Serial1.println(seek + ": " + String(numToReg));
      addToHreg(lut[i].addr, numToReg, lut[i].numAddr);
    }
  }
} /**/

//function that returns one line from begin index until next \n
String getLine(String sData, int begindex) {
  String line = "";
  int j = begindex;
  char c = sData.charAt(j);
  while (c != 10) {
    line += c;
    j++;
    c = sData.charAt(j);
    yield();
  }
  return line;
}

//adds to both ethernet and rtu registers
void addToHreg(int beginAddress, uint32_t number, int numRegisters) {
  //check if 2 registers are needed and mask the data accordingly
  //0xFFFF0000 to keep the first 16bit for first register
  //0x0000FFFF to keep the last 16bit for second register
  if (numRegisters == 2) {
    if (rtuFlag == 0) {
      Serial1.println("TCP setting " + String(number) + "to register " + String(beginAddress));
      mbE.Hreg(beginAddress + 1, number & 0x0000FFFF);
      mbE.Hreg(beginAddress, number & 0xFFFF0000);

    } else if (rtuFlag == 1) {
      Serial1.println("RTU setting " + String(number) + "to register " + String(beginAddress));
      mbRTU.Hreg(beginAddress, number & 0xFFFF0000);
      mbRTU.Hreg(beginAddress + 1, number & 0x0000FFFF);
    } else if (rtuFlag == 2) {
      Serial1.println("RTU setting " + String(number) + "to register " + String(beginAddress));
      mbIP.Hreg(beginAddress, number & 0xFFFF0000);
      mbIP.Hreg(beginAddress + 1, number & 0x0000FFFF);
    }
    //mbIP.Hreg(beginAddress + 1, number & 0x0000FFFF);
    //mbIP.Hreg(beginAddress, number & 0xFFFF0000);
  } else {
    if (rtuFlag == 0) {
      Serial1.println("TCP setting " + String(number) + "to register " + String(beginAddress));
      mbE.Hreg(beginAddress, number);
    } else if (rtuFlag == 1) {
      Serial1.println("RTU setting " + String(number) + "to register " + String(beginAddress));
      mbRTU.Hreg(beginAddress, number);
    } else if (rtuFlag == 2) {
      Serial1.println("RTU setting " + String(number) + "to register " + String(beginAddress));
      mbIP.Hreg(beginAddress, number);
    }
  }
}

//probably no longer needed, still kept it to not lose it just in case
/*void doSplit(Vector_GCM &vect) {
  String pltxt = "";
  for (int x = 0; x < vect.datasize; x++) {
    pltxt += (char)vect.plaintext[x];
  }
  int i = 0;
  int j = 0;
  String tempData = "";
  while (j < vect.datasize) {
    if (pltxt.charAt(j) == 10 ||pltxt.charAt(j) == 13) {
      splitData[i] = tempData;
      if (i > 1) {
        Serial1.print(i);
        Serial1.print(" register: ");
        if (i != 16) {
          float numToReg=numberFromString(tempData, "(", ")");
          Serial1.println(numToReg);
          mbE.Hreg(i, numToReg);
        } else {
          float numToReg=multipleNumbersFromString(tempData, "(", ")", "(", ")");
          Serial1.println(multipleNumbersFromString(tempData, "(", ")", "(", ")"));
          mbE.Hreg(i, numToReg);
        }
      }
      tempData = "";
      i++;
    } else {
      tempData += pltxt.charAt(j);
    }
    j++;
  }
}*/

//returns float number from a given string in between 2 delimiters (mostly "(" and ")") filtering out any unwanted characters
float numberFromString(String sData, const char *begin, const char *end) {
  /*find indexes of delimiters*/
  int subStringBegin = sData.indexOf(begin) + 1;
  int subStringEnd = sData.indexOf(end);
  /*create substring between delimiters*/
  String sub = sData.substring(subStringBegin, subStringEnd);
  String conversion = "";
  for (int x = 0; x < sub.length(); x++) {
    char selectChar = sub.charAt(x);
    if (selectChar == 45 || selectChar == 46 || selectChar > 47 && selectChar < 58) {
      conversion += selectChar;
    }
  }

  return atof(conversion.c_str());  //some are bigger than uint16_t so output=wrong in modbus
}
//same as above, only with 2 numbers from 1 string which are beign put into a given array, was needed for 1-1:31.4.0, but no longer in use
void multipleNumbersFromString(String sData, const char *begin1, const char *end1, const char *begin2, const char *end2, uint16_t ar[]) {
  /*get indexes from the set delimiters*/
  int firstSubStringBegin = sData.indexOf(begin1);
  int firstSubStringEnd = sData.indexOf(end1);
  int lastSubStringBegin = sData.lastIndexOf(begin2);
  int lastSubStringEnd = sData.lastIndexOf(end2);

  /*create the substrings and conversion string*/
  String firstSub = sData.substring(firstSubStringBegin, firstSubStringEnd);
  String lastSub = sData.substring(lastSubStringBegin, lastSubStringEnd);
  String conversion = "";

  /*go through first substring and put together the conversion string with the number*/
  for (int x = 0; x < firstSub.length(); x++) {
    char firstChar = firstSub.charAt(x);
    if (firstChar == 46 || firstChar > 47 && firstChar < 58) {
      conversion += firstChar;
    }
  }
  /*output the conversion string and input the number into the given array*/
  Serial1.println("multipleNumbersFromString returned" + conversion);
  ar[0] = atof(conversion.c_str());
  /*reset conversion string*/
  conversion = "";
  /*do the same thing with the next string*/
  for (int x = 0; x < lastSub.length(); x++) {
    char lastChar = lastSub.charAt(x);
    if (lastChar == 45 || /**/ lastChar == 46 || lastChar > 47 && lastChar < 58) {
      conversion += lastChar;
    }
  }
  Serial1.println("multipleNumbersFromString returned" + conversion);
  ar[1] = atof(conversion.c_str());
}

//function to receive data
void receiveData() {
  unsigned int serial_count = 0;
  //if serial is available, wait a bit to receive all the data, then handle it
  if (Serial.available() > 0) delay(250);
  while ((Serial.available() > 0) && (serial_count < MAX_SERIAL_STREAM_LENGTH)) {
    allData[serial_count] = Serial.read();
    //check if beginning of data is valid
    if (allData[0] != 0xDB) {
      //erase buffer and break out of loop
      while (Serial.available() > 0) {
        Serial.read();
      }
      break;
    }
    serial_count++;
  }
}

//function to get minimum register index
uint16_t getMin(lutStruct lut[]) {
  uint16_t result = lut[0].addr;
  for (int i = 1; i < lutLength; i++) {
    uint16_t temp = lut[i].addr;
    if (temp < result) result = temp;
  }
  return result;
}
//function to get maximum register index
uint16_t getMax(lutStruct lut[]) {
  uint16_t result = lut[0].addr;
  for (int i = 1; i < lutLength; i++) {
    uint16_t temp = lut[i].addr;
    if (temp > result) result = temp;
  }
  return result;
}
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
void loop() {

  if ((millis() - prevAPMillis >= APTimeout) && apMode == 2) {
    WiFi.softAPdisconnect(true);
    Serial1.println("AP2 closed");
    Serial1.println(apMode);
    apMode = 0;
    Serial1.println(apMode);
    /*if(ssid!=""&&pass!=""){
      Serial1.println("here");
      Serial1.println(WiFi.config(wifiIP, wifiGateway, wifiSubnet)? "Ready":"Failed");
      Serial1.println(WiFi.begin(ssid,pass)? "Ready":"Failed");
      while (WiFi.status() != WL_CONNECTED) {
        delay(500);
        Serial.print(".");
      }
    }*/
  } else if (apMode == 0) {

    //Serial1.println(apMode);
    //call receive data function
    receiveData();
    //check if data is valid
    if ((allData[0] == 0xDB) && (allData[1] != 0) && (allData[2] != 0)) {
      //check if vector initialisation has failed
      if (init_vector_GCM_decryption(my_vector, "my_vector", mykey, myAAD) != 0) {
        Serial1.println("ERROR");
        delay(100);
        return;
      }
      //decrypt the received text
      decrypt_text(my_vector);
      //non blocking delay to print out vector for debugging and write new values to registers
      if (millis() - prevMillis >= interval) {
        prevMillis = millis();
        print_vector(my_vector);
        obisToHReg(my_vector, lookupTable);
      }
    }
    //modbus ethernet and rtu tasks

    if (rtuFlag == 1) {
      mbRTU.task();
      Serial1.println("RTU Task");
    } else if (rtuFlag == 0) {
      mbE.task();
      Serial1.println("TCP task running");
    } else if (rtuFlag == 2) {
      if (WiFi.status() == WL_CONNECTED) {
        mbIP.task();
        Serial1.println("WiFI task running");
      }
      else{
        
        while (WiFi.status() != WL_CONNECTED) {
          
          delay(500);
          Serial1.print(".");
        }
      }
    }
  }
  //yield to be safe if nothing happens for some time
  yield();
}

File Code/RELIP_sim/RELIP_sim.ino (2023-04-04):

/*
  RELIP - Simulator
  Feil Charel
  BTS-IOT 2
  2022/2023
*/

#include <Crypto.h>
#include <AES.h>
#include <GCM.h>

#define REQ_PIN D1  //set data request pin

//variables for nonblocking delay
int prevMillis = 0;
int interval = 10000;

const unsigned int MAX_PLAINTEXT_LEN = 1200;

// Text to encrypt:
const char mytext[MAX_PLAINTEXT_LEN] = R"(
/Lux5\253663653_B

1-3:0.2.8(42)
0-0:1.0.0(230315155342W)
0-0:42.0.0(53414731303330373030303236353638)
1-0:1.8.0(000017.901*kWh)
1-0:2.8.0(055437.011*kWh)
1-0:3.8.0(001080.968*kvarh)
1-0:4.8.0(000828.854*kvarh)
1-0:1.7.0(00.000*kW)
1-0:2.7.0(03.454*kW)
1-0:3.7.0(00.025*kvar)
1-0:4.7.0(00.000*kvar)
0-0:17.0.0(069.0*kVA)
1-0:9.7.0(00.000*kVA)
1-0:10.7.0(03.450*kVA)
1-1:31.4.0(100*A)(-100*A)
0-0:96.3.10(1)
0-1:96.3.10(0)
0-2:96.3.10(0)
0-0:96.7.21(00914)
1-0:32.32.0(00011)
1-0:52.32.0(00012)
1-0:72.32.0(00011)
1-0:32.36.0(00001)
1-0:52.36.0(00001)
1-0:72.36.0(00001)
0-0:96.13.0()
0-0:96.13.2()
0-0:96.13.3()
0-0:96.13.4()
0-0:96.13.5()
1-0:32.7.0(236.0*V)
1-0:52.7.0(233.0*V)
1-0:72.7.0(235.0*V)
1-0:31.7.0(004*A)
1-0:51.7.0(004*A)
1-0:71.7.0(004*A)
1-0:21.7.0(00.000*kW)
1-0:41.7.0(00.000*kW)
1-0:61.7.0(00.000*kW)
1-0:22.7.0(01.160*kW)
1-0:42.7.0(01.146*kW)
1-0:62.7.0(01.147*kW)
1-0:23.7.0(00.007*kvar)
1-0:43.7.0(00.007*kvar)
1-0:63.7.0(00.010*kvar)
1-0:24.7.0(00.000*kvar)
1-0:44.7.0(00.000*kvar)
1-0:64.7.0(00.000*kvar)
!6B4A)"/*R"(
/Lux5\Charel
1-3:0.2.8(42)
0-0:1.0.0(221231160517W)
0-0:42.0.0(53414731303330373030313931333639)
1-0:1.8.0(20000*kWh)
1-0:2.8.0(012183.984*kWh)
1-0:3.8.0(003428.126*kvarh)
1-0:4.8.0(010884.835*kvarh)
1-0:1.7.0(02.606*kW)
1-0:2.7.0(00.000*kW)
1-0:3.7.0(01.006*kvar)
1-0:4.7.0(00.000*kvar)
0-0:17.0.0(069.0*kVA)
1-0:9.7.0(02.808*kVA)
1-0:10.7.0(00.000*kVA)
1-1:31.4.0(100*A)(-100*A)
0-0:96.3.10(1)
0-1:96.3.10(0)
0-2:96.3.10(0)
0-0:96.7.21(00031)
1-0:32.32.0(00006)
1-0:52.32.0(00005)
1-0:72.32.0(00004)
1-0:32.36.0(00000)
1-0:52.36.0(00000)
1-0:72.36.0(00000)
0-0:96.13.0()
0-0:96.13.2()
0-0:96.13.3()
0-0:96.13.4()
0-0:96.13.5()
1-0:32.7.0(232.0*V)
1-0:52.7.0(229.0*V)
1-0:72.7.0(231.0*V)
1-0:31.7.0(004*A)
1-0:51.7.0(004*A)
1-0:71.7.0(003*A)
1-0:21.7.0(01.005*kW)
1-0:41.7.0(00.925*kW)
1-0:61.7.0(00.675*kW)
1-0:22.7.0(00.000*kW)
1-0:42.7.0(00.000*kW)
1-0:62.7.0(00.000*kW)
1-0:23.7.0(00.272*kvar)
1-0:43.7.0(00.369*kvar)
1-0:63.7.0(00.364*kvar)
1-0:24.7.0(00.000*kvar)
1-0:44.7.0(00.000*kvar)
1-0:64.7.0(00.000*kvar)
!AF4A
)"*/;
const char myvname[] = "AES-128 GCM";                 // vector name
char mykey[] = "EBD3E604BA79E1D7CF9D2D1AB1033204";    // Key for SAG1030700089067 (16 byte)
char myAAD[] = "3000112233445566778899AABBCCDDEEFF";  // 17 byte (in Hex 34 character)
char myIV[] = "46656943680067C800000000";             // "SAGgp + "0x0067C8" + 4 byte counter

struct Vector_GCM {
  const char *name;
  static const byte keysize = 16;
  unsigned int datasize;
  static const byte authsize = 17;
  static const byte ivsize = 12;
  static const byte tagsize = 12;
  byte key[keysize];
  byte plaintext[MAX_PLAINTEXT_LEN];
  byte ciphertext[MAX_PLAINTEXT_LEN];
  byte authdata[authsize];
  byte iv[ivsize];
  byte tag[tagsize];
};

unsigned long counter = 0;

Vector_GCM my_vector;

void setup() {
  //Begin serial at baud rate 115200bit/s and 8n1
  Serial.begin(115200, SERIAL_8N1);
  //define data request pin as input
  pinMode(REQ_PIN, INPUT);
  delay(2500);

  // initialise the vector
  if (init_vector_GCM_encryption(my_vector, myvname, mykey, mytext, myAAD, myIV) != 0) {
    //reset ESP if vector initialisation failed
    ESP.reset();
  }
  delay(2500);
}

void loop() {
  //check if nonblocking delay has passed and if data is requested
  if ((digitalRead(REQ_PIN) == LOW) && (millis() >= prevMillis + interval)) {
    prevMillis = millis();

    /****** encrypt ******/
    encrypt_text(my_vector);

    //begin to write
    //starting byte
    Serial.write(0xDB);
    //calculate title length
    unsigned int titleLen = my_vector.ivsize - 4;
    Serial.write(titleLen);
    //write iv to Serial
    for (byte i = 0; i < my_vector.ivsize - 4; i++) {
      Serial.write(my_vector.iv[i]);
    }
    //write 0x82? because it's needed
    Serial.write(0x82);

    //calculate total length
    uint16_t totalLen = 17 + my_vector.datasize;

    //total length (16bit) needed to be split in 2 to write each byte separately to Serial
    Serial.write(highByte(totalLen));
    Serial.write(lowByte(totalLen));

    //write the Security byte
    Serial.write(0x30);
    //write counter to serial
    for (int i = 8; i < my_vector.ivsize; i++) {
      Serial.write(my_vector.iv[i]);
    }
    //write ciphertext to serial
    for (unsigned int i = 0; i < my_vector.datasize; i++) {
      Serial.write(my_vector.ciphertext[i]);
    }
    //add the tag to the end
    for (byte i = 0; i < my_vector.tagsize; i++) {
      Serial.write(my_vector.tag[i]);
    }
    //end

    /****** increment counter ******/
    increment_counter(my_vector, counter);
  }
  //yield to feed the watchdog
  yield();
}

// initialize the vector_structure from c-strings
int init_vector_GCM_encryption(Vector_GCM &vect, const char *vect_name, char *key,
                               const char *plaintext, char *aad, char *iv) {
  if (strlen(key) != (vect.keysize * 2)) {
    return -1;
  }
  if (strlen(aad) != (vect.authsize * 2)) {
    return -1;
  }
  if (strlen(iv) != (vect.ivsize * 2)) {
    return -1;
  }
  vect.name = vect_name;                     // init vector name
  c_string_hexbytes_2_bytes(key, vect.key);  // array passed by ref
  vect.datasize = strlen(plaintext);         // init plaintext
  for (unsigned int i = 0; i < vect.datasize; i++) {
    vect.plaintext[i] = mytext[i];
    yield();
  }
  c_string_hexbytes_2_bytes(aad, vect.authdata);  // array passed by ref
  c_string_hexbytes_2_bytes(iv, vect.iv);         // array passed by ref
  return 0;
}

void encrypt_text(Vector_GCM &vect) {
  GCM<AES128> *gcmaes128 = 0;
  gcmaes128 = new GCM<AES128>();
  gcmaes128->setKey(vect.key, gcmaes128->keySize());
  gcmaes128->setIV(vect.iv, vect.ivsize);
  gcmaes128->encrypt(vect.ciphertext, vect.plaintext, vect.datasize);
  gcmaes128->computeTag(vect.tag, vect.tagsize);
  delete gcmaes128;
}

void decrypt_text(Vector_GCM &vect) {
  GCM<AES128> *gcmaes128 = 0;
  gcmaes128 = new GCM<AES128>();
  gcmaes128->setKey(vect.key, gcmaes128->keySize());
  gcmaes128->setIV(vect.iv, vect.ivsize);
  gcmaes128->decrypt(vect.plaintext, vect.ciphertext, vect.datasize);
  delete gcmaes128;
}

void increment_counter(Vector_GCM &vect, unsigned long &counter) {
  unsigned long counter_high, counter_low;
  counter++;
  counter_high = counter / 65536;
  counter_low = counter % 65536;
  vect.iv[8] = highByte(counter_high);
  vect.iv[9] = lowByte(counter_high);
  vect.iv[10] = highByte(counter_low);
  vect.iv[11] = lowByte(counter_low);
}
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
